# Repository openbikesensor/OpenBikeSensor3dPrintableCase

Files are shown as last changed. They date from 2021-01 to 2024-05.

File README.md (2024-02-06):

# OpenBikeSensor Case

This repository contains the 3d-printable models for OpenBikeSensor enclosures.

[Project Website](https://openbikesensor.org) |
[Model selection](https://www.openbikesensor.org/device/) (German) |
[3D printing instructions](https://www.openbikesensor.org/docs/hardware/general/case/) (German)

If you encounter any problems or have feature requests, please open an issue on
GitHub. If you need assistance related to the contents of this repository,
please ask in the [project forums](https://forum.openbikesensor.org).

## Cloning
If you want to build your own case using openscad instead of using the
readymade exports or if you want to start the customizer be aware
that you need to clone including git submodules:

```
git clone --recursive https://github.com/openbikesensor/OpenBikeSensor3DPrintableCase
# ... or if you forgot the --recursive argument, you can run this in the
# repository's directory later:
git submodule update --init --recursive
```

## About the files

We expect a recent version of OpenSCAD, for development we currently use OpenSCAD 2021.

This repository contains a lot of files for different options

* The `export/` folder contains the latest prebuilt `.stl` files for 3D printing.
  You can use those unless you want to make customizations. If you contribute
  changes to the models, you can refresh the models you changed using the
  ``make export-all`` command. If your ``openscad`` binary does not reside
  in ``/usr/bin/openscad`` you can specify its location by overriding the
  ``OPENSCAD`` variable like so (substitute your specific openscad path): ``make -j OPENSCAD=/Applications/OpenSCAD.app/Contents/MacOS/OpenSCAD``
* The `legacy/` folder contains old versions of the case, including lots of
  variants that were created but unmaintained. These were built with
  proprietary software packages and often available in their native format(s)
  and therefore mostly uneditable for most of the community. A lot of these
  files are also available in STEP format, and of course exported as STL for
  printing. We keep these files around for reference and convenience.
* The `lib/` folder contains common OpenSCAD files with library functions and
  modules, as well as exports of other objects that can be imported in the part
  files, e.g. to check dimensions.
* The `src/` folder contains OpenSCAD scripts for all parts. Not all parts are
  needed for printing a working enclosure. Please check the documentation
  (links on top) to assemble your custom list of parts for the variant you want
  to build.
* The `render/thumbnails/` folder contains rendered views of the parts. These images
  should be refreshed with changes to the parts using the `make thumbnails`
  command if you plan to submit your changes. They are used in this `README.md`.
* The `variables.scad` file contains all variables used in any of the parts.
  You can customize everything by editing this file, or passing new variable
  values on the OpenSCAD command line.

## The Standard Variant

There is a notion in the OpenBikeSensor community to label one combination of
parts and a certain version of the electronics the "Standard Model" (read about
it [here](https://www.openbikesensor.org/docs/hardware/general/models/)). This
is meant to get you started, without having to check for compatibility and
without cross referencing multiple parts of the documentation to build your own
version of the device.

> **Warning**
> We only keep the rail shapes constant between versions. When printing make sure that your ``MainCase`` and ``MainCaseLid`` come from the same release. The same is true for ``DisplayCase`` Top and Bottom. The Idea is that OpenBikeSensors can be mounted on a different bike with older version mounts, but the current version lid won't necessarily fit onto last years case.

To get a standard variant, print these parts:

```
MainCase/GpsAntennaLid
MainCase/MainCase
MainCase/UsbCover
MainCase/MainCaseLid
DisplayCase/DisplayCableStrainRelief (2x)
DisplayCase/DisplayCaseBottom
DisplayCase/DisplayCaseTop
Mounting/StandardMountAdapter
Mounting/SeatPostMount
Mounting/LockingPin
Mounting/HandlebarRail
```

## Compatibility

The parts are compatible with the OpenBikeSensor PCB Version `00.03.12`. Other
versions, both older and newer, might work, but are untested.

## Part list

This is a list of all available parts, and a description of what they are used for.

### Main case

The main case of the device enclosure. This will contain most of the
electronics. The core part are a `MainCase` and a `MainCaseLid`, which is
installed with five M3x8 bolts in the lid, matching the five threaded heatset
inserts in the body.

The PCB is installed into the main body with 3 heat-set inserts and M3x8 bolts.
One additional heat-set insert is required for the `GPSAntennaLid` (see below).
This totals 9 inserts to be placed after printing.

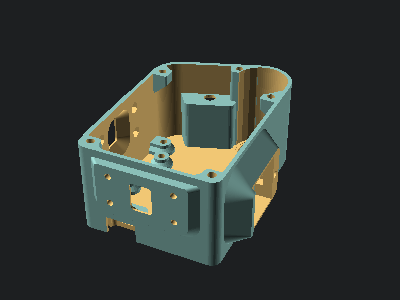
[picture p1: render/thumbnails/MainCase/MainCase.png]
MainCase/MainCase


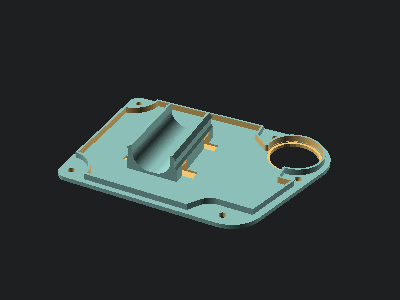
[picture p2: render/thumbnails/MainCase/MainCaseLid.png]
MainCase/MainCaseLid


#### GPS antenna lid

The `GpsAntennaLid` covers the part of the main enclosure with the GPS antenna.
It is held in place by only one M3x8 bolt and can be removed to reveal the
antenna, behind which there is an access hole for the Micro-USB receptable of
the ESP32 dev board -- very useful for debugging or developing the firmware.

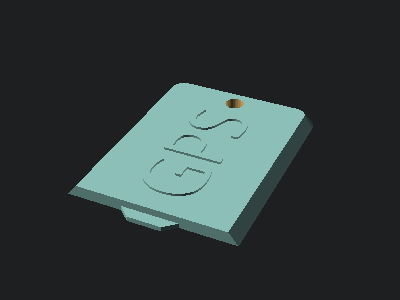
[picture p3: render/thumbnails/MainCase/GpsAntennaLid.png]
MainCase/GpsAntennaLid


#### USB-C port cover

The `UsbCover` is small plug for the USB-C port on the bottom of the device,
which is used for charging the battery. This plug is held in place by 2 pairs
of 3x3x3mm neodymium magnets.

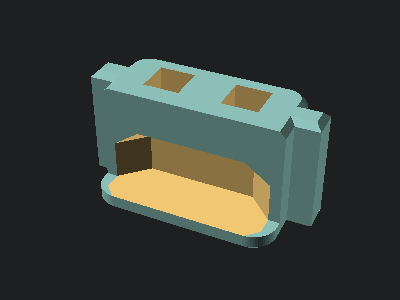
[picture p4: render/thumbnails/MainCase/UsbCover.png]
MainCase/UsbCover


### Display case

The display case consists of two halfs, `DisplayCaseTop` and
`DisplayCaseBottom`. The display case contains the I2C display and a push
button and is attached to the main device with a cable that exits through a
hole in the bottom part.

The bottom part contains 3 threaded heat-set inserts and a pocket for two
20x10x1.9mm neodymium magnets. The magnets hold the display in the rail on the
handlebar (see `HandlebarRail`).

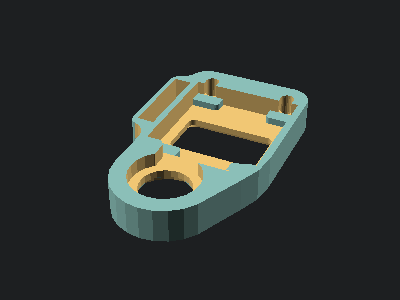
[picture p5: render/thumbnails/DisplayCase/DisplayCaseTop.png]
DisplayCase/DisplayCaseTop


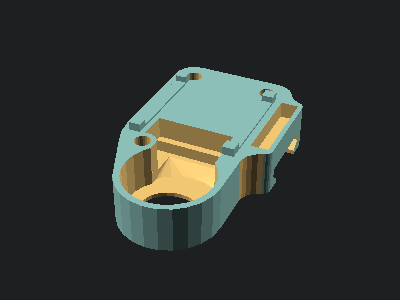
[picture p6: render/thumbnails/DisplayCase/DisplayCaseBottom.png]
DisplayCase/DisplayCaseBottom


#### Display cable strain relief

*Print two copies of this.*

The `DisplayCableStrainRelief` holds the display cable firmly in place inside
the display case to prevent strain on the solder joints or crimped connectors
inside. The two halves are pushed into the hole at an angle one after the
other, and then screwed together with two M3x8 bolts and hex nuts.

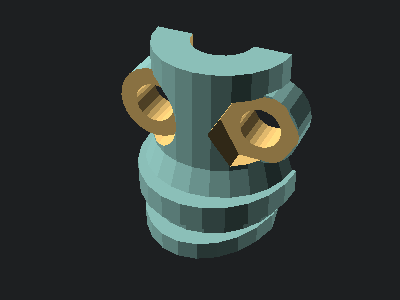
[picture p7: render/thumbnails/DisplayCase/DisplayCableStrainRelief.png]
DisplayCase/DisplayCableStrainRelief


### Mounting

#### Standard mount adapter

The `StandardMountAdapter` is screwed onto the main enclosure. It contains a
channel for the display cable to sit in, pressing it firmly against the outer
wall of the main case and relieving any strain from its connector inside.

This adapter is used to attach the device to the mount that is permanently
affixed to the bike. There may be different adapters in the future for
different attachment needs, but this one is the default.

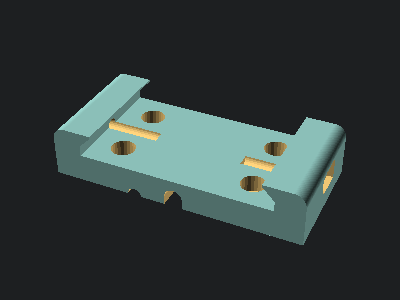
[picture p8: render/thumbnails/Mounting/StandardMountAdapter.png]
Mounting/StandardMountAdapter


#### Seat post mount

The `SeatPostMount` gets attached to the seat post of the bicycle with zip ties.

*Hint: A piece of an old bicycle tube can prevent it from turning or shifting.*

This is a counterpart to the `StandardMountAdapter`, which can slide onto this
part's rail and be held in place with a `LockingPin`.

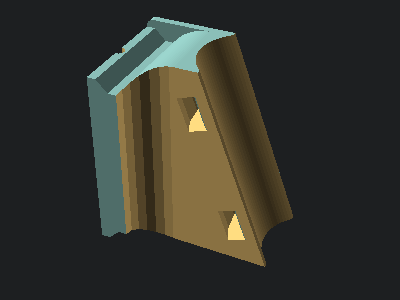
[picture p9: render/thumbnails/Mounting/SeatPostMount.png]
Mounting/SeatPostMount


#### Top tube mount

The `TopTubeMount` gets attached to the top tube of the bicycle frame, similar
to the seat post mount.

*Hint: A piece of an old bicycle tube can prevent it from turning or shifting.*

This is also compatible with the `StandardMountAdapter` and `LockingPin`. Make
sure to use a "Top Rider" variant main case (see below for details).

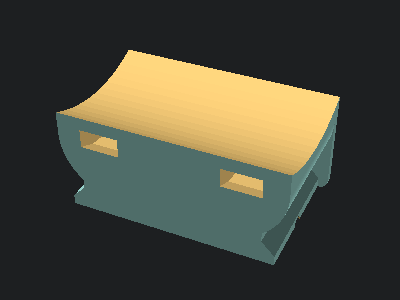
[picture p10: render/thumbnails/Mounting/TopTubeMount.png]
Mounting/TopTubeMount


#### Locking pin

Screw an M3x16 to M3x20 bolt through the `LockingPin` part, such that the
bolt's head sits on the long handle's side. Now you have a pin that you can
push into the hole in the `StandardMountAdapter` and turn 180 degrees, holding
the pin, and the device, in place.

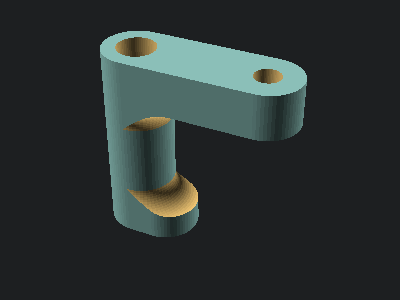
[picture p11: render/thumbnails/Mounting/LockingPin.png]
Mounting/LockingPin


#### Handlebar rail

Attach the `HandlebarRail` to the handlebar of your bike with two zip ties or a single
hose clamp. Again, a piece from an old bicycle tube can prevent turning and shifting.

The large wall contains a pocket for two 20x10x1.9mm neodymium magnets, pushed
in one after the other. Make sure to consider their polarity to match those of
the display. The display can now slide onto this rail and is held in place by
the magnets.

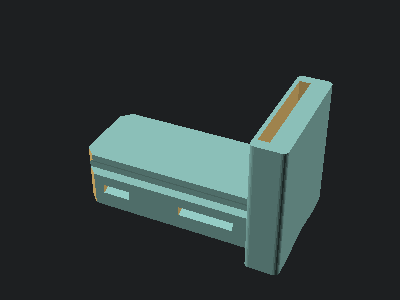
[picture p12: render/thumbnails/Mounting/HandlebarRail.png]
Mounting/HandlebarRail


An alternative Handlebar rail can be mounted like most bike computers with a
rubber o ring;
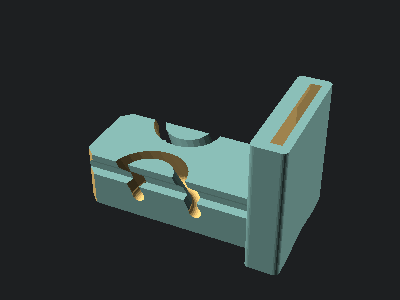
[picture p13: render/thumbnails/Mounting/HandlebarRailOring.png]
Mounting/HandlebarRailOring


Often you find magnets where one magnet is strong enough for your display - you
can use a platic decoy to save on magnets in these cases
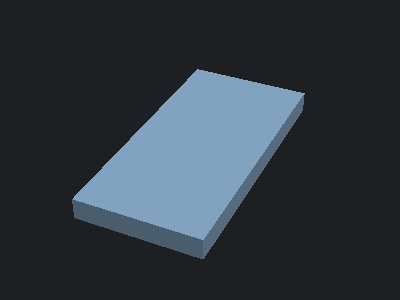
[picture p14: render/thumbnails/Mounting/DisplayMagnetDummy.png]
Mounting/DisplayMagnetDummy


#### Bike rack mount

The bike rack mount can be used to attach a "Top Rider" main case to a standard
bicycle rack. It consists of two parts, the `BikeRackMountSide` (which is
required twice) and `BikeRackMountCenter` or `BikeRackMountCenterLongitudinal`.

The side parts are mounted on the longitudinal rails of the rack, either above
or hanging below. They are connected with two rods (aluminium or wood) that
form cross beams, cut to sized depending on the width of the bike rack. In the
center of these rods sits the center piece, which has the attachment rail for
the sensor.

In a rotated version, the rods are aligned longitudinally, a difference center
piece (`BikeRackMountCenterLongitudinal`, third image) is used to rotate the
OBS correctly. Use this if you need your bike rack's longitudinal tubes for
attaching cargo, and you want to mount the OBS on the cross beams of the rack.

The rods can be affixed to the 3D printed parts by gluing them in place, once
they have been sized and fitted to your rack.

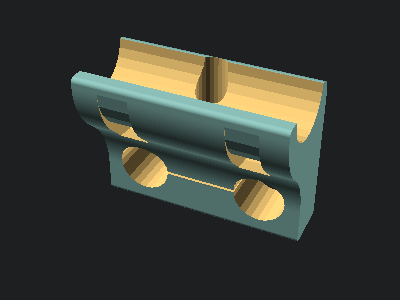
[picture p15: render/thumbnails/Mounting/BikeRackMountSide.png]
Mounting/BikeRackMountSide


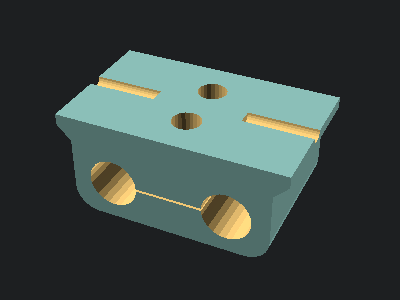
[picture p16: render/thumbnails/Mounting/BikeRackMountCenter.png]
Mounting/BikeRackMountCenter


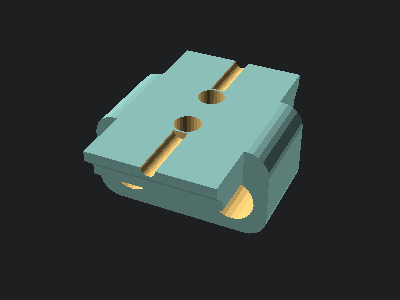
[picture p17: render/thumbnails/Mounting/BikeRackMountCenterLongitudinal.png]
Mounting/BikeRackMountCenterLongitudinal


#### Attachment cover

If you have a main case that has both attachment points (top rider and back
rider), you may want to cover the one of them that you are not using, such that
the screw holes and (optional) cable hole are not left open. The
`AttachmentCover` is a simple cover that fits the screw pattern.

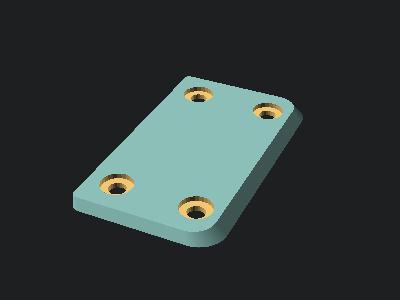
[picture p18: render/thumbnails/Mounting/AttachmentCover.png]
Mounting/BikeRackMountSide


#### Back rider to top rider adapter

This adapter allows the use of a "back rider" main case on a "top rider" mount.
Print a second locking pin as well.

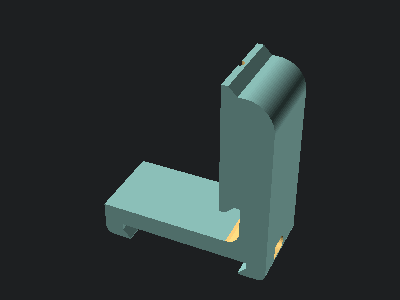
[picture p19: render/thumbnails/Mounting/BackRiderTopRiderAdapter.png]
Mounting/BackRiderTopRiderAdapter


## Customization

There are tons of variables in the `variables.scad` file, mostly dimensions,
which can be adjusted to suit your needs. Some of these variables are however
not necessarily wise to be changed, as other dimensions might inadvertently
depend on them, or they might produce invalid results in certain ranges.

However, some options are meant to be changed to suit your specific needs. The
defaults get you most of the way, but certainly, some users will need a
different set of features, so here is a list of options you might want to
change:

### Print settings

Some options exist to control sizes and features that have been added just for
3D printing ease. Configure these to match your printing setup. The defaults
should work for most printers, but if you modify your settings greatly (e. g.
to print faster), you might also need to change these model parameters:

```
extrude_width
enable_easy_print
layer_height
default_clearance
```

### Top Rider vs. Back Rider

A "top rider" variant main case has an attachment port on the bottom (when
mounted), while a "back rider" has it on the front. The "traditional" OBS case
therefore is a back rider variant, as it used to always sit behind the seat
post, attached horizontally. However, many cyclists configure their bikes in a
way that there is not enough room for a whole OBS below the seat, so a
different way of attaching the OBS is needed.

Top riders can sit on the top tube, the luggage rack, or anywhere else where
there is support from below. Moving the attachment point on the main case makes
it simple to design compatible mounts with their rail on top, without a
complicated structure that "goes up and around" to provide a backwards-facing
rail.

A single case can have both top rider and back rider attachment ports. They
don't necessarily need to have an adapter attached, though it is recommended to
do so in order to fill the screw and cable holes.

To configure whether to generate top and/or back riders, set the following
variables. The `_cable` variables control whether the corresponding attachment
port (if it exists) has a hole for the cable or not.

```
MainCase_back_rider
MainCase_top_rider
MainCase_back_rider_cable
MainCase_top_rider_cable
```

The `Mounting/BackRiderTopRiderAdapter` is available for people who have a back
rider and would like to use a top rider mount. The opposite is not available.

### Dimensions

* General
  * `m3_screw_diameter_loose`: A hole for an M3 bolt has this diameter. The
    bolt is not meant to grab this hole, but slide into and out of it ("loose"
    fit). For (almost) each bolt, there is a corresponding threaded metal part
    (nut or insert), so increase this value if your bolts are hard to get where
    they need to go. Print `Calibration/ScrewHoles` to find a good value for
    your printer.
  * `m3_hex_nut_diameter`: The outer circle around a hex nut's hexagon has this
    diameter. This is **not** the same as the "wrench size" from [DIN
    934](https://www.fasteners.eu/standards/DIN/934/) (dimension `S`), but its
    nominal value is `2 / sqrt(3) * S`. For M3, this equals `6.35mm` nominally.
    Increase this for more clearance. Print `Calibration/HexNuts.stl` to find a
    good value for your printer.
* `SeatPostMount`
  * `SeatPostMount_angle`: Set to the angle that your seat post is away from
    the vertical in degrees (usually around 20). This ensures that the device
    will sit horizontally behind the seat post.
  * `SeatPostMount_diameter`: Set to the diameter of your seat post (in mm).
    The default for most bicycles today is 28.
  * `SeatPostMount_length`: Increase this to lengthen the mount,
    shifting the device further backwards on your bike. You might consider
    angular force, so don't set it too high, but this can help if your mount is
    hard to reach, or if the device disappears underneath your seat,
    potentially blocking GPS signal.
* `HandlebarRail`
  * `HandlebarRail_tube_radius`: The radius (half diameter) of your handlebar,
    in mm.

### Logo customization

The `Makefile` supports generating the case with different logos. For now, the
only parts that are customizable with logos are `MainCase/MainCase` and
`MainCase/MainCaseLid`. Please check the instructions in
[`logo/README.md`](./logo/README.md) for creating your own logo version.

## Legacy parts

The files of legacy versions are available in the ``.stl`` format for 3D
printing. But these are discretized versions of more universal 3D Geometry that
can be read and edited by CAD software.

This is a grown project and in the past contributions have been made with
different CAD Programs. Some parts were designed/modified in Autodesk inventor
(filenames `*.ipt`), some were designed in Fusion360 (filenames `*.f3d`), but
for most parts a step file (`*.stp, *.step`) is available which can be opened
by most CAD Programs. For your contributions in CAD software of your choice it
would be great if you could also follow the practice of submitting your changes
in both `.stl` for 3D-Printing and `.step` for later editing - and maybe the
native format of your CAD software on top.

OpenSCAD is a special case of course: Here submitting `.stl` (for now) and the
`.scad` file is sufficient. 

### Customizer webservice

To run the customizer webservice you run it from the dockerfile (and be sure
that you cloned the repo recursively before building the cointainer:

```
git submodule update --init --recursive
docker build . -t customizer
docker run --rm -p 8001:80 customizer 
```

Whereafter you should be able to access your customizer on your host on port 8001.

Alternatively you can launch the python module directly using uvicorn,
but that is only recommended for dev setups an d will be described
in the module readme.

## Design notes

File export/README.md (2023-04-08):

# For the most recent release you can find the files conveniently zipped [here under "assets"](https://github.com/openbikesensor/OpenBikeSensor3dPrintableCase/releases)

This folder contains the stl files for convenience. It is recommended however to download the latest released files as a zipped bundle [here under "assets"](https://github.com/openbikesensor/OpenBikeSensor3dPrintableCase/releases) instead.

> **Warning**
> We only keep the rail shapes constant between versions. When printing make sure that your MainCase and Lid as well as DisplayCase Top and Bottom come from the same case version. The Idea is that OpenBikeSensors can be mounted on a different bike with older mounts, but the current version lid won't necessarily fit onto last years case.

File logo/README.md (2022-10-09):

# Logo generator

This folder contains logo files to be generated into the STL files, adding a
customizable logo to your cases. The script generates a "main" part and a
"highlight" part, where the main part is the normal case file with the logo cut
out, and the "inner" part is the logo. This can be used in multi-part printing,
e.g. in Prusa Slicer or Ultimaker Cura. In general you will need to follow these steps:

* Find your logo as a vector graphics file (e.g. SVG)
* Scale the logo to the right dimensions, using the frame templates
* Choose inverted or normal mode, and a logo thickness
* Generate the STL files with GNU make
* Import the two STL files into your slicer as a multipart print, or print just
  the main part with a color change at an early layer
  
The script will only work on linux.

## Features

* Use any vector graphics, simple placement in template
* Inverted or normal style logo
* Customize logo depth (number of layers)
* Auto generate in Makefile

## Guide

### Preparing the logo

* Open the logo you would like to use in [Inkscape](https://inkscape.org/)
* Make sure the logo is only a shape path. Colors, gradients and even the
  thickness of lines are ignored. Use the options in the "Path" menu of
  Inkscape, e.g. "Object to Path" and "Union", to generate a single path
  object. Remove its border, fill it black.
* Duplicate `logo/template` to `logo/MyLogoName` (choose a name) and edit the
  files in this folder in Inkscape, copy-paste your logo into it. Transform the
  logo to place it where you would like to print it.
* Delete the gray frame shape, leaving only a correctly sized document with the
  logo placed where you want it.

### Choosing options

Depending on your logo shape and the colors you are going to use it to print,
you might want to **invert the logo**. For an inverted logo, the space
surrounding the logo is separated for printing, the logo becomes part of the
main body instead. Use this

* when you want to print the logo and body in the same color, or
* when your logo should be printed in an translucent filament and the space
  around it should be covering in an opaque filament (the combination of two
  translucent filaments is discouraged as the colors mix and look ugly), or
* depending on the shape of your logo, e.g. when very thin features or acute
  angles are present and you want to influence the printing order.

If you use a custom layer height other than 0.2mm, or you need more layers of
logo, change the corresponding variables in `variables.scad`. Some opaque
filaments could work if just one layer is applied, but for best results, at
least two layers should be chosen. Each layer will need a filament change
though, so try to keep the number of layers low. The default example is a 0.2mm
layer height, and two layers of logo printing, which results in a logo depth of
0.4mm.

### Generate the STL files

The following make targets are available:

```bash
make logos # generate all logo files
make logo-MyLogoName # generate all files for the logo in logo/MyLogoName
make logo-MyLogoName-normal # only normal mode
make logo-MyLogoName-inverted # only inverted mode
```

The files generated are placed here:

```
export/logo/$logo_name/MainCase-$mode-main.stl
export/logo/$logo_name/MainCase-$mode-highlight.stl
```

A pair of two such files forms the whole case, where the `main` file is the
normal body of the object (case or lid), and the `highlight` file is the
cut-away part. Import both simultaenously into your slicer to form a multi-part
object for multi-color printing.

The `$mode` can be "normal" or "inverted". An inverted logo is used if the
color of the logo should match the color of the walls and remainder of the
object, effectively printing the bottom side (while printing) in a different
color, *except* for the logo. This may be easier to print or desired for
aesthetical reasons, depending on the logo and filaments you use.

### Importing into Prusa Slicer

If you're not using Prusa Slicer or a derivative thereof, you will need to find
your own solution. If you are using Ultimaker Cura, see below.

For Prusa Slicer, multipart printing is very simple to set up, if your printer
supports any type of command to switch filaments.  Marlin firmware can be
compiled for most printers with support for the M600 command. Printers with
physical support for multi-material printing of course should be supported out
of the box.

* Import the `export/logo/MyLogoName/MainCase-normal-main.stl` (or *inverted*
  instead of *normal*) file into Prusa Slicer as usual. It should be placed in
  the center of your build plate automatically.
* In the right sidebar, locate your part. Under "Editing", click the icon, then
  choose "Add Part" > "Load...", and select the corresponding
  `...-highlight.stl` file.
* You now have a multipart print. Configure everything as normal.
* If your printer only has one extruder, but supports the M600 command, you can
  still choose 2 extruders under "Printer Settings" > "General" >
  "Capabilities" > "Extruders". In the "Custom G-Code" section, under "Tool
  change G-code", you might have to enter `M600`.
* You should then be able to choose the two extruders for the different parts
  in the parts list in the right sidebar. This way the slicer generates
  separate toolpaths for both parts in each layer, and places the M600 command
  in between those paths. The printer will then pause and wait for the user to
  change the filament and confirm to resume.

If you don't mind multiple gcode-Files, your printer does not support `M600` and
your nozzle shape allows you to print around multiple layers, you can export the
gcode for each color by turning the other part into a support blocker. If the bed
keeps being heated after the print (eg. no `M140 S0` command at the end of the print),
you can change filament and start with the next file. Printing brims can be problematic
if the printed part only touches the build plate on smaller areas than the rest of the
body does.

### Importing into Ultimaker Cura

To print in Ultimkaer Cura with two colors, follw these steps:
* Click on the folder in the upper left corner and choose the first file. Make sure that on the left side extruder 1 is selected.
* Click again on the folder and choose the second file. Now select extruder 2 on the left side. Both files should now be visible next to each other.
* Select both parts (click, hold shift and click on the other part). Rightclick to bring up the context menu, select `Merge Models`.
* Normally, they should align now. If not, align them manually.
* Press `slice` and continue as normal.

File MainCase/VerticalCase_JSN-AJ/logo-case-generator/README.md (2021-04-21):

# Logo Case Generator

This is a tool made with OpenSCAD, to take the main case or lid file and add a logo to
it. The script generates a "main" part and a "inner" part, where the main part
is the normal case file with the logo cut out, and the "inner" part is the
logo. This can be used in multi-part printing, e.g. in Prusa Slicer. In general
you will need to follow these steps:

* Find a logo as a vector graphics file (e.g. SVG)
* Scale the logo to the right dimensions, using the frame template
* Choose inverted or normal mode, and a logo thickness
* Generate the two STL files
* Import the two STL files into your slicer as a multipart print, or print just
  the main part with a color change at an early layer

## Features

* Use any vector graphics, simple placement in template
* Inverted or normal style logo
* Customize logo depth (number of layers)
* Only generates a lid for now, will be extended for the main case as well

## Guide

### Preparing the logo

* Open the logo you would like to use in [Inkscape](https://inkscape.org/)
* Make sure the logo is only a shape path. Colors, gradients and even the
  thickness of lines are ignored. Use the options in the "Path" menu of
  Inkscape, e.g. "Object to Path" and "Union", to generate a single path
  object. Remove its border, fill it black.
* Open `frame-lid.svg` or `frame-maincase.svg` in Inkscape and copy-paste your logo into it. Transform the
  logo to place it where you would like to print it.
* Delete the gray frame shape, leaving only a correctly sized document with the
  logo placed where you want it.
* Save the file as a different file, in this example we'll use `my-logo-framed.svg`.

### Choosing options

Depending on your logo shape and the colors you are going to use it to print,
you might want to **invert the logo**. For an inverted logo, the space
surrounding the logo is separated for printing, the logo becomes part of the
main body instead. Use this 

* when you want to print the logo and body in the same color, or
* when your logo should be printed in an translucent filament and the space
  around it should be covering in an opaque filament (the combination of two
  translucent filaments is discouraged as the colors mix and look ugly), or
* depending on the shape of your logo, e.g. when very thin features or acute
  angles are present and you want to influence the printing order.

You will also need to choose a thickness, or `logo_depth`. This should be a
multiple of your layer height. Some opaque filaments could work if just one
layer is applied, but for best results, at least two layers should be chosen.
Each layer will need a filament change though, so try to keep the number of
layers low. The default example is a 0.2mm layer height, and two layers of logo
printing, which results in a logo depth of 0.4mm.

### Generate the STL files

First, you need to have [OpenSCAD](https://openscad.org/) installed.

Run the following commands:

```bash
openscad -D 'mode="main"' -D 'logo_file="my-logo-framed.svg"' -D 'logo_depth=0.4' logo-lid.scad -o lid-my-logo-main.stl
openscad -D 'mode="inner"' -D 'logo_file="my-logo-framed.svg"' -D 'logo_depth=0.4' logo-lid.scad -o lid-my-logo-inner.stl
```

If you chose an inverted logo, also add `-D 'inverted=true'` to both
commands. If your logo is a very complex shape, and the result looks wrong, try
setting and increasing the `logo_convexity` parameter as well, from its default
10 upwards, e.g. to 20 or 30.

You can also combine the inverted `inner` with a with an inverted `main` with 
`-D 'logo_file="empty_logo.svg"'` to achieve a bridged logo with multiple files.

### Importing into Prusa Slicer

If you're not using Prusa Slicer or a derivative thereof, you will need to find
your own solution.

For Prusa Slicer, multipart printing is very simple to set up, if your printer
supports any type of command to switch filaments.  Marlin firmware can be
compiled for most printers with support for the M600 command. Printers with
physical support for multi-material printing of course should be supported out
of the box.

* Import the `lid-my-logo-main.stl` file into Prusa Slicer as usual. It should
  be placed in the center of your build plate automatically.
* In the right sidebar, locate your part. Under "Editing", click the icon, then
  choose "Add Part" > "Load...", and select the `lid-my-logo-inner.stl` file.
* You now have a multipart print. Configure everything as normal.
* If your printer only has one extruder, but supports the M600 command, you can
  still choose 2 extruders under "Printer Settings" > "General" >
  "Capabilities" > "Extruders". In the "Custom G-Code" section, under "Tool
  change G-code", you might have to enter `M600`.
* You should then be able to choose the two extruders for the different parts
  in the parts list in the right sidebar. This way the slicer generates
  separate toolpaths for both parts in each layer, and places the M600 command
  in between those paths. The printer will then pause and wait for the user to
  change the filament and confirm to resume.

If you don't mind multiple gcode-Files, your printer does not support `M600` and 
your nozzle shape allows you to print around multiple layers, you can export the 
gcode for each color by turning the other part into a support blocker. If the bed 
keeps being heated after the print (eg. no `M140 S0` command at the end of the print), 
you can change filament and start with the next file. Printing brims can be problematic
if the printed part only touches the build plate on smaller areas than the rest of the 
body does.

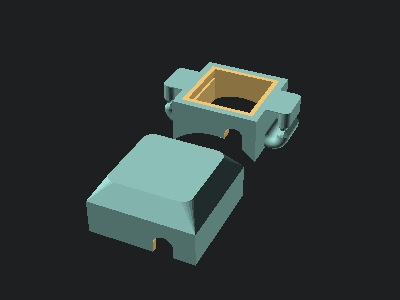
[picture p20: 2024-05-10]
render/thumbnails/LiteCase/HandlebarButton.png

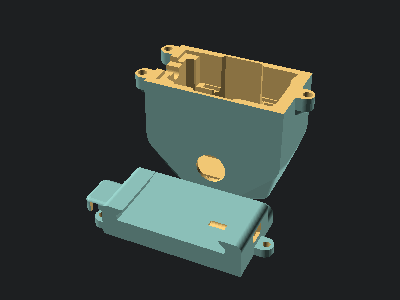
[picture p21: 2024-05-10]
render/thumbnails/LiteCase/LiteCase.png

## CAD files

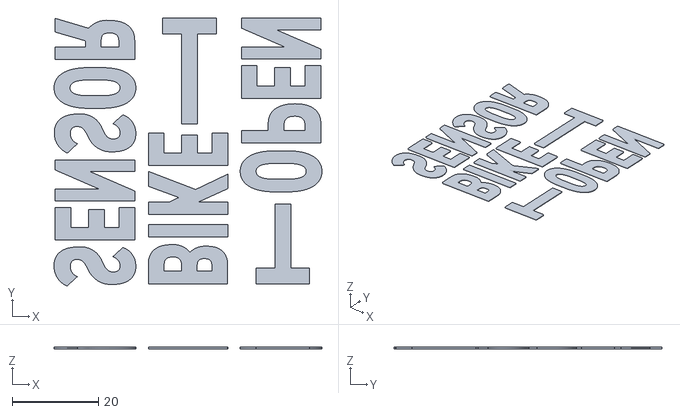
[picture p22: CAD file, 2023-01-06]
export/logo/OpenBikeSensor/MainCase-normal-highlight.stl
62.2 x 62.2 x 0.4

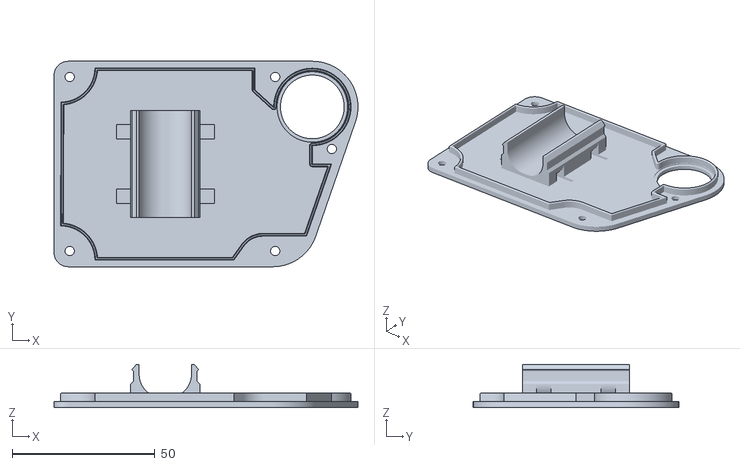
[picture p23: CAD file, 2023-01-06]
export/MainCase/MainCaseLid.stl
106.5 x 72.0 x 15.1

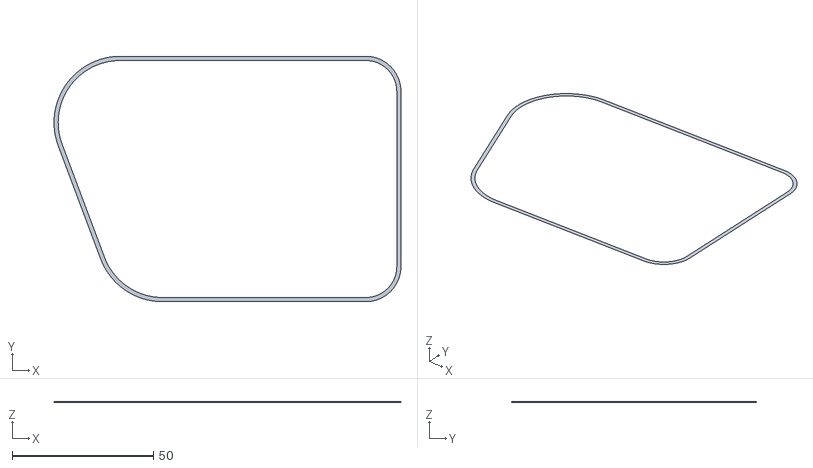
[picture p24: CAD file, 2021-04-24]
MainCase/VerticalCase_JSN-AJ/experimental/manual_brim_for_maincase.stl
123.0 x 87.0 x 0.2

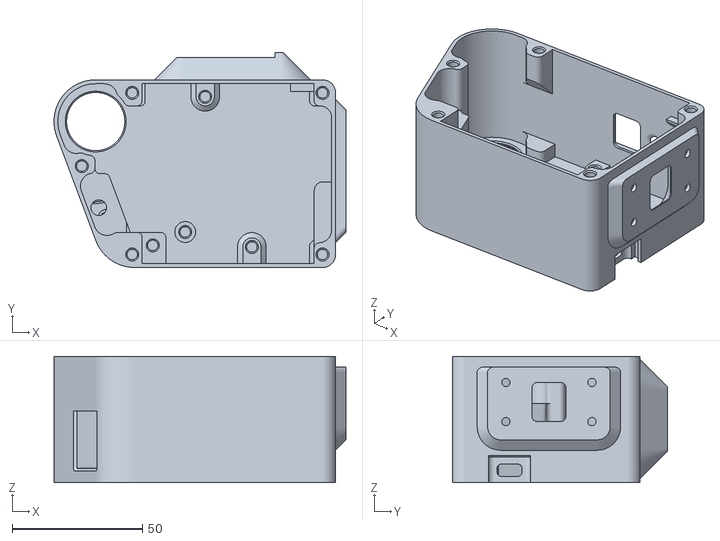
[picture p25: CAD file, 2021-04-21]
MainCase/VerticalCase_JSN-AJ/experimental/OBS-MainCase-A-001_MainCase_without_logo_v0.1.0.stl
112.0 x 82.5 x 48.4

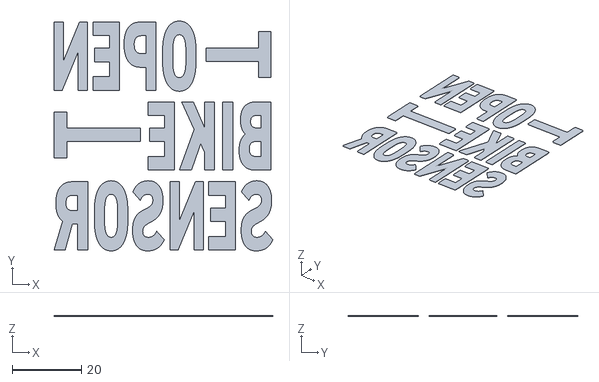
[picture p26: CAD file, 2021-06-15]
MainCase/VerticalCase_JSN-AJ/OBS-MainCase-B-002_Lid_with_0.4mm_OBS-logo_v0.1.0_bottom.stl
63.1 x 66.2 x 0.4

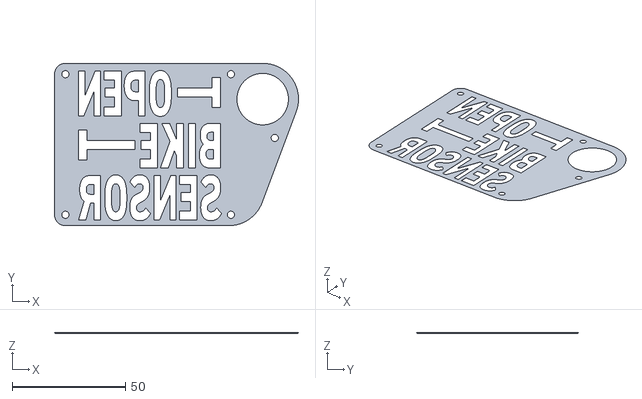
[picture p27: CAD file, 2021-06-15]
MainCase/VerticalCase_JSN-AJ/OBS-MainCase-C-002_Lid_v0.1.0_with_0.4mm_OBS-logo_bottom-inverted.stl
107.6 x 71.6 x 0.4

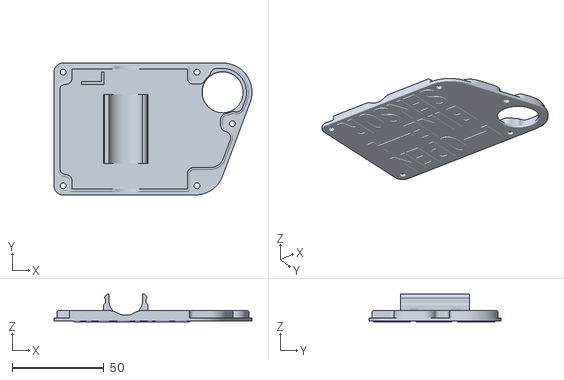
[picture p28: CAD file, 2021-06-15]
MainCase/VerticalCase_JSN-AJ/OBS-MainCase-C-002_Lid_v0.1.0_with_0.4mm_OBS-logo_top-inverted.stl
108.0 x 72.0 x 15.1

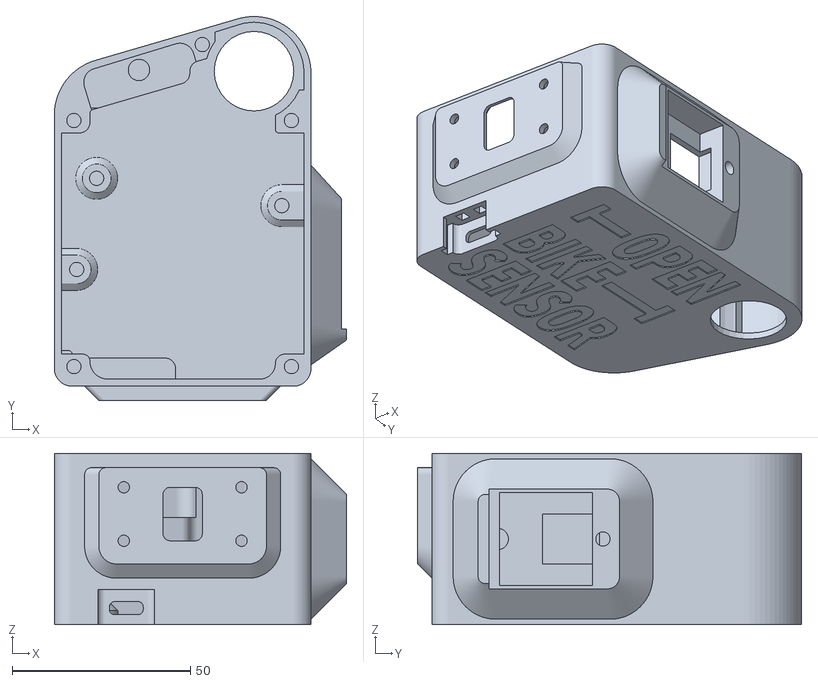
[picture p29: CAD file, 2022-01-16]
export/logo/OpenBikeSensor/MainCase-normal-main.stl
82.0 x 107.7 x 48.0

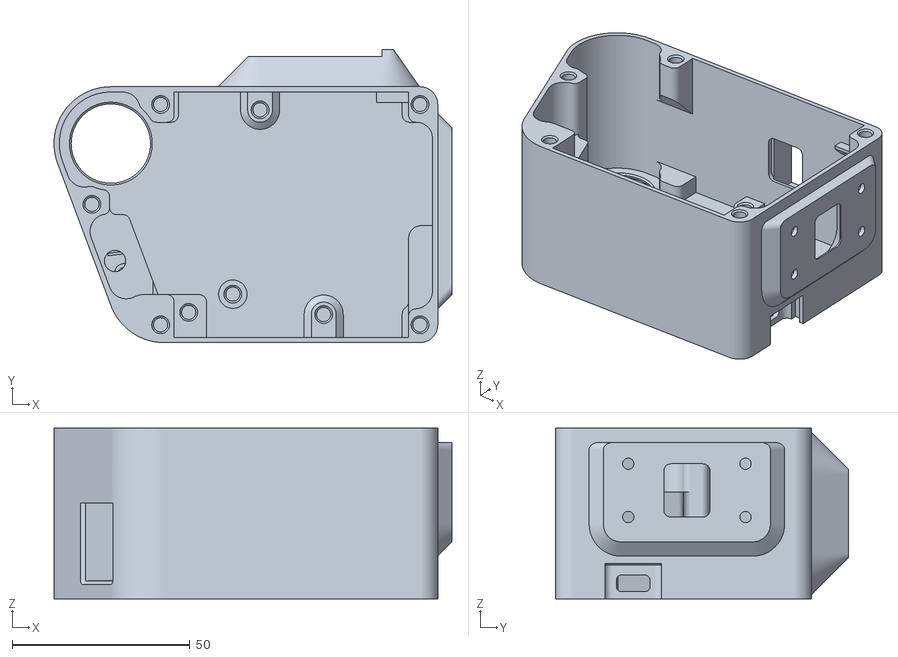
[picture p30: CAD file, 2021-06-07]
MainCase/VerticalCase_JSN-AJ/OBS-MainCase-D-001a_empty_logo_top.stl
112.0 x 82.5 x 48.0

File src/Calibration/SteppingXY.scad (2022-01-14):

// The object generated by this file can be used to print a calibration cross
// of known target size, in order to compute the correct steps/mm values for
// the printer. The positive x-axis arm has a little mark in it, make sure to
// align it correctly in your slicer or remember the alignment when you take it
// off your print bed.
//
// Please print this and calibrate your printer step settings, such that all
// dimensions print correctly, before using any of the other calibration tools.
// This object does not measure your z distance (that would print way too
// long), but it is much easier to manually move your print head along z
// through G-code and measure the resulting height change, compared to good
// horizontal measurements.

use <../../lib/Calibration.scad>

length = 100;
width = 5;
height = 0.8;

union() {
  difference() {
    translate([0, 0, height/2])
    cube([length, width, height], true);

    translate([length/2 - width/2, 0, height])
    cylinder(d=min(1.5, width/2), h=height, center=true, $fn=32);
  }

  rotate([0, 0, 90])
  translate([0, 0, height/2])
  cube([length, width, height], true);
}

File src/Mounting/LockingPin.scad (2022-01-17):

include <../../variables.scad>

// $fa = 1;
// $fs = 0.1;
$fn = 64;

module LockingPinRoundRect(h, l) {
  hull() {
    cylinder(h=h, d=LockingPin_diameter);

    translate([l - LockingPin_diameter, 0, 0])
    cylinder(h=h, d=LockingPin_diameter);
  }
}

module LockingPinFillet(handle_length) {
  intersection() {
    difference() {
      LockingPinRoundRect(LockingPin_fillet_radius, handle_length);

      // fillet on foot
      translate([0, 0, LockingPin_fillet_radius])
      rotate_extrude()
      translate([LockingPin_diameter/2 + LockingPin_fillet_radius, 0, 0])
      circle(r=LockingPin_fillet_radius);
    }

    cylinder(r=LockingPin_diameter / 2 + LockingPin_fillet_radius, h=LockingPin_fillet_radius);
  }
}

module LockingPin() {
  difference() {
    union() {
      // base cylinder
      cylinder(h=LockingPin_height, d=LockingPin_diameter);

      // foot
      translate([0, 0, LockingPin_height - LockingPin_foot_height])
      LockingPinRoundRect(LockingPin_foot_height, LockingPin_diameter + LockingPin_fillet_radius);

      // handle
      LockingPinRoundRect(LockingPin_handle_height, LockingPin_handle_length);

      // handle fillet
      translate([0, 0, LockingPin_handle_height])
      LockingPinFillet(LockingPin_handle_length);

      // foot fillet
      translate([0, 0, LockingPin_height - LockingPin_foot_height])
      mirror([0, 0, 1])
      LockingPinFillet(LockingPin_diameter + LockingPin_fillet_radius);
    }

    // holes
    union() {
      // hole in handle, for wire attachment
      translate([LockingPin_handle_length - LockingPin_diameter, 0, -1])
      cylinder(d=LockingPin_small_hole_diameter, h=LockingPin_handle_height+2);

      // hole in main shaft, for holding screw
      translate([0, 0, -1])
      cylinder(d=m3_screw_diameter_tight, h=LockingPin_height+2);
    }
  }
}

if (orient_for_printing) {
  LockingPin();
} else {
  translate([0, 0, LockingPin_height])
  rotate([180, 0, 0])
  LockingPin();
}

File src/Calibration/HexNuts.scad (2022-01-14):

use  <../../lib/Calibration.scad>

HolePatternM3HexNut();

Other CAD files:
MainCase/VerticalCase_JSN-AJ/OBS-MainCase-D-002_Lid_v0.1.0_empty_logo_top.stl
export/logo/OpenBikeSensor/MainCaseLid-inverted-main.stl
export/logo/OpenBikeSensor/MainCaseLid-normal-highlight.stl
export/logo/OpenBikeSensor/MainCaseLid-inverted-highlight.stl
export/logo/OpenBikeSensor/MainCaseLid-normal-main.stl
MainCase/VerticalCase_JSN-AJ/OBS-MainCase-B-002_Lid_v0.1.0_with_0.4mm_OBS-logo_top.stl
export/logo/OpenBikeSensor/MainCase-inverted-highlight.stl
export/logo/OpenBikeSensor/MainCase-inverted-main.stl
MainCase/VerticalCase_JSN-AJ/OBS-MainCase-A-001_MainCase_without_logo_v0.1.4.stp
src/Calibration/ScrewHoles.scad
DisplayCase/DisplayCase32mm/KnopfZusammenbau.iam
DisplayCase/DisplayCase32mm/Oberschale.ipt
DisplayCase/DisplayCase32mm/Oberschale.stl
DisplayCase/DisplayCase32mm/Schelle32.ipt
DisplayCase/DisplayCase32mm/Schelle32.stl
DisplayCase/DisplayCase32mm/Zwischenstueck.ipt
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

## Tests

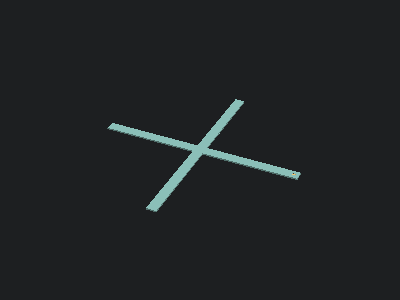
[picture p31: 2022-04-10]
render/thumbnails/Calibration/SteppingXY.png

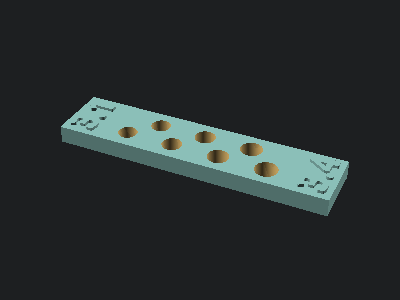
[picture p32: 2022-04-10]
render/thumbnails/Calibration/ScrewHoles.png

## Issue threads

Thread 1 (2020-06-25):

Reduce Number of Screws

tobst, 2020-06-25:
Choose a minimum of total screws as well as a minimum of different types. If possible, choose screws that are widely available (hardware store, etc.).

opatut, 2022-01-16:
The current version takes only M3x8 screws and a single M3x18 screw (I think) for the locking pin. There is still a need for corresponding nuts and heatset inserts, but this is way better than before. No more M3x45 screws, which are useless for any other project and not included in the ususal amazon M3 bolt collection packages etc. ;)

I think we can close this.

Closed 2022-01-16.

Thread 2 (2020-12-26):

Include a hole under magnet housing to be able to slide magnets out of their housing

rotger711, 2020-12-26:
In this version it is not possible to get the two magnets out of their housing. With a hole in the middle under the magnet housing this is made possible. Necessary if two OBS systems and sliding fixture are exchanged with opposite magnet (south / north) orientation.

opatut, 2022-01-16:
We're talking about the display rail here, I think. A hole was added long ago and it is also present in the `openscad` version.

Closed 2022-01-16.

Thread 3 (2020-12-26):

change OBS holding device

mega-stoffel, 2020-12-26:
The current OBS holding device has a gap in it to keep the holding screw. I'd suggest to make this gap over the whole width of this device.
The advantage would be, to be able to turn the holding device around and mount the OBS in a tilted position. I hope, to get a better GPS position, if the OPS is not looking directly into my body, but a bit more into the clear sky.

opatut, 2022-01-16:
It has been mirrored to the other side for a while now.

Closed 2022-01-16.

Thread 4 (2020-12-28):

Simons Gehäuse braucht 3-4mm mehr Höhe

Halbelunge, 2020-12-28:
Prozessor kollidiert mit Akku im Deckel wenn die Leiste zu hoch ist.

opatut, 2022-01-16:
I think this is solved by using actually the right SMD headers.

Closed 2022-01-16.

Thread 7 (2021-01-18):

GPS Antennenposition

Steffeng5, 2021-01-18:
wegen 3D Druck Präzisionsproblemen könnte die Antenne fürs GPS auch von oben eingeführt werden, da diese ja sowieso mit einer Deckplatte abgedeckt wird. So ist es nicht zwingend nötig auf Zehntel Millimeter genau zu drucken

mdoersam, 2021-01-18:
Wäre es ok, dann die Möglichkeit, das Gehäuse an der Stelle zu montieren komplett zu entfernen? Nach unserem Gespräch heute war das ja anscheinend sowieso nicht mehr der Fall

opatut, 2022-01-16:
Das wurde längst umgesetzt :tada:

Closed 2022-01-16.

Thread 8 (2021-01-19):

DisplayParts in VerticalCase Directory

Steffeng5, 2021-01-19:
There are display mount parts in /MainCase/VerticalCase/. By mistake I think?

mdoersam, 2021-01-19:
Can you list the filenames for easier confirmation?

Steffeng5, 2021-01-19:
OBS-A-001-AlternativeMount22mmSlide.stl
OBS-A-002-AlternativeMount22mmTop.stl
OBS-A-003-AlternativeMount22mmBottom.stl

Closed 2022-01-16.

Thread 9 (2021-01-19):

Add One Layer to "with LED holes" variant

Steffeng5, 2021-01-19:
For better water resistance there should maybe one 0.2mm layer to cover the LED holes. This should be thin enough to see the leds but protect against rain.

mdoersam, 2021-01-19:
Not sure how needed this might be.
Plan A is to add hot glue to plug the holes and have it transparent.
Plan B could be to just add a small modifier in the Slicer and have your effect if someome doesn't want to go the hotglue-route

opatut, 2022-01-16:
Superseded by #35.

Closed 2022-01-16.

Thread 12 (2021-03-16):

More clearance for PCB

opatut, 2021-03-16:
The current case fits the PCB exactly. We should add some clearance, so that on inexact prints or a bit oversize PCBs (cheap manufacturers from china don't always mill it to spec) don't sit too tightly. There is no reason for not adding some clearance around it, it is mounted securely using 3 bolts, and we have enough space to work with. I'd say ~0.5mm in each direction should be good.

The tight fit (pressing in the PCB) might result in damage or stress and later damage in soldering joints.

opatut, 2022-01-16:
This was done in the legacy versions already and also implemented in openscad.

Closed 2022-01-16.

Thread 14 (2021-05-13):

More clearance for magnet holes

gluap, 2021-05-13:
It would be great to add .1mm to .2mm of clearance to the magnet holes in all directions. Currently the holes are designed exactly to dimension of the magnets. But in 3D printing, especially at higher layer heights used by most people for larger objects this makes it very hard to slide the magnets in. The reason is that even with a well-calibrated printer the edges of each layer resemble a semicircle (or circular sector). And while the "average edge of deposited material" will be on-spot for a perfectly calibrated printer, the bellies of the circles or circle-sectors unavoidably protude beyond the planned edge of the layer, making the hole slightly smaller.

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

I know that this can be compensated for in some slicers ("enlarge holes in layers" type settings). However the setting it does not apply to all orientations of printing (because in some orientations the slicer does not detect the magnet holes as "holes" as they are not holes in the topographic sense. E.g. the pocket for the magnet in the display case.).

Mario (who is printing most of our cases) has locally modified the models to have more clearance, but it would be great if there was a bit of space to wiggle the magnets in the upstream model, as it would avoid a lot of test-prints on the user side. While a too-big hole can be compensated for by a bit of cyanacrylate or even a leftover piece of brim wedged in on the side, a too-small hole is hard to enlarge when it is only 3mm wide and its opening even smaller.

Alternatively if there is a proven method to wiggle the magnets in, this could be documeneted. The Issue I have is that Neodymium magnets aren't supposed to be heated above the 80°C that are needed to soften PETG.

I would have put this in terms of a pull request but I believe the current version of the Fusion360 files aren't in the repo yet.

opatut, 2021-05-13:
I totally agree.

> Neodymium magnets aren't supposed to be heated above the 80°C that are needed to soften PETG

I've heard of people successfully "soldering" them in place though. I can't promise it, but apparently for a short duration it doesn't totally wreck them.

> I would have put this in terms of a pull request but I believe the current version of the Fusion360 files aren't in the repo yet.

It's difficult, yeah. The latest modifications were, I think, done in Inventor from importing the step model, or something like that. There is sadly zero support for a PR-based workflow with these software packages, even exporting and importing fusion projects is a pain. We're looking into alternatives. Do you know of any good ones?

gluap, 2021-05-13:
@opatut No, I don't know a better solution for versioning 3d models. Unless one manages them in the workflow of one of the software packages (I believe fusion allows collaboration on models, but have no experience in using it), versioning of 3D models mostly comes down to managing binary blobs. Merging is impossible so the workflow with the least overhead is when one person manages the model. Some VCSes allow exclusive checkouts for this kind of work to ensure only one person at a time can work on un-mergable file format. Git is not one of them though.

Another possible path would be to build the model entirely in openscad (where everything is source code and thus merges are easy). But in my experience that becomes painful because of very long render times when one approaches the complexity of the cases. Also the learning curve of openscad is rather steep.

tobst, 2021-05-20:
Attempted to fix by  73d93de4da1ab3c2d892554190c8c89588ca5360
However I see the risk of tuning it just to my printer now.

tobst, 2021-05-20:
I added 0.1mm in all directions, but magnets can be pulled out with the counterpart now.

gluap, 2021-05-20:
With 0.15mm I added to the step file for experiments I observed that magnets could be pulled out, too. As stated above however I think a hole that works on most printers but needs glue (or a bit of brim wedged in) is preferrable to one that needs lots of test prints going to the garbage on most printers. Ill print the update tonight to see how it works out here. 0.1mm sounds snug but still insertable. Before I wasn't able to build the display cases at all without modification, the magnet just wouldn't drop into the recess no matter what.

tobst, 2021-05-20:
Should we supply an scad script to extract the critical part into a small test object which can be printed in a few minutes?

gluap, 2021-05-20:
I usually cut the interesting sections out in the slicer. If the model position can be assumed as fixed though, an openscad script could be provided that directly enlarges magnet holes parametrically. It could even be used to generate a set of test pieces with different clearances.

gluap, 2021-05-20:
An alternative solution that just sprang into my mind would be to enlarge the clearance but leave a very narrow notch to wedge the magnet against, which could hold it but would require less force to insert it. Crude ascii-art for illustration of a square magnet hole below:

```
+---v---+
|       |
>       <
|       |
+---^---+

gluap, 2021-05-23:
Following up on @opatut's lead about the magnets surviving "soldering" into the plastic: according to [supermagnete.de](https://www.supermagnete.de/faq/Wie-heiss-duerfen-Magnete-werden), the cubic magnets can be heated above 80° without damaging them thanks to their favourable aspect ratio. For the flat magnets in the display cases heat may be more of an issue and partial loss of magnetization is expected.

tobst, 2021-05-24:
After testing diferent clearances and your suggeste shape I am in favor for a script with default coordinates but different ones as an option to modify it to your needs.

tobst, 2021-05-24:
Event heating them up is a difficult task becaus they will always stick to each other or your heated metal tool.

gluap, 2021-06-19:
Regarding the cubic magnets of the main case:

I have made some experiments and arrived at a geometry that allows inserting the magnets easily while still keeping them in place a little:
- I added a cubic clearance of around 0.2 around the magnets of the MainCase in all three spatial directions.
- Clearance was added such that one layer worth of filament was left with the original dimensions. That way there is a ridge around the opening that allows to push the magnet in but which holds them in place and keeps them from jumping out. If they are too lose, they can be fixed in place using 2 component acrylic (or other suitable glue).
- Inserting them was a breeze: Have a tower of cubic magnets, push two into the MainCase and two into the USB cover, and they stay there first try.

Attached: Adapted USB cover + matching STL.

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
[adapted_plug.zip](https://github.com/openbikesensor/OpenBikeSensor3dPrintableCase/files/6680777/adapted_plug.zip)

gluap, 2021-07-08:
@tobst  what do you think of the above? I have rudimentary openscad scripts to cut this kind of holes into the case, but unless you think it makes sense I'd rather not invest the time to make them "pull-request" ready.

opatut, 2022-01-16:
I guess with the new openscad branch this becomes trivial. I'm closing this ticket in favor of the more general #34.

Closed 2022-01-16.

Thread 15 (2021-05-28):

Add loops for a little string to attach the pin to the main case

opatut, 2021-05-28:
A little hole in the pin, and one in a fitting location on the main case, would allow me to attach the pin with a string to the main body and never lose one _again_ ;)

gluap, 2021-09-28:
I just noticed that the pin already has a fitting hole. The string can be wound around one of the case screws on the case side to provide the requested functionality.

opatut, 2022-01-16:
Done, at least on `openscad` branch.

Closed 2022-01-16.

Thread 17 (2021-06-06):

OBS-Display-A-005_Kabelbinder_Schiene_v0.1.0: Change Side of the Magnet-Pocket

Carolinitzny, 2021-06-06:
The Magnet-Pocket is on the upper side in build direction, where the printer has to bridge. This is prone to inaccuracy and therefore makes putting the second magnet in very hard (if the printing wasn't as clean :)  ).
Would be nice, if the magnet-pocket is on the other side where the bridging is more accessible and easier to clean up.

tobst, 2021-06-06:
This part has been bothering me since i designed it. I would be happy to redesign. Can you provide a simple sketch to clarify your suggestion?

Carolinitzny, 2021-06-06:
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
The light green part is for the handlebar, the darker green is the part where the magnets fit in

opatut, 2022-01-16:
Hi @Carolinitzny, your suggestion was applied on the `openscad` branch at least, maybe even before in the legacy files.

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

Closed 2022-01-16.

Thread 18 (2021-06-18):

More space for display

gluap, 2021-06-18:
Currently a lot of suppliers of OLED displays seem to be switching to a new OLED display type which is slightly larger than the one previously delivered. Four out of five suppliers we tried delivered the larger display type, with some giving outright wrong measurements for the displays. The displays were electronically compatible with OBS.

The new type display board is 27.5-28mm wide and 28-29mm long, with the glass being as wide as the board, making it impossible to cut the boards down to size.

I believe an increased display opening would already allow for use of both style (small and large) boards in the same display case.

I attached a 3d Model (stl in zip) of the large-type displays as measured. The active area of the oled display is marked as a slight cutout from the display glass that is not present in the actual device.

[largedisplay.zip](https://github.com/openbikesensor/OpenBikeSensor3dPrintableCase/files/6679185/largedisplay.zip)

opatut, 2022-01-16:
Is this just a clearance problem or do we need a different geometry? I don't understand the new shape, maybe you can provide pictures, @gluap ?

gluap, 2022-01-16:
The overall geometry is the same, the difference is only the display board (and glass) width and height. You can find a working case for such displays here: https://github.com/gluap/OpenBikeSensor3dPrintableCase/tree/oversize_display/DisplayCase/SlideOnDisplay/SpecialVersions .

Essentially having the display width and height parametrized (and the hole through which one looks at the display as well) would allow for this. Clearance alone won't do it properly as the scale factors in the two dimensions of the rectangle do not necessarily match.

opatut, 2022-01-17:
So these are enough?

```
DisplayCaseTop_pcb_width = 26.5;
DisplayCaseTop_pcb_height = 27.2;
DisplayCaseTop_window_width = 21.5;
DisplayCaseTop_window_height = 12.5;
```

:)

gluap, 2022-01-19:
Yes that looks sufficient!

gluap, 2022-04-10:
with parametrized display size the issue should be solved.

Closed 2022-04-10.

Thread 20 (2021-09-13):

Welche Dateien sind die richtigen?

derlucas, 2021-09-13:
Hallo Zusammen,
aus der Doku https://www.openbikesensor.org/docs/hardware/general/case/ geht nicht hervor, welche Dateien man drucken muss.

Ich habe dem Rat entsprechend das Vertical Case gewählt und stehe vor der Frage OBS-MainCase A B C D?

Eine kurze Aufstellung der Files für ein Gehäuse samt Halterung an der Sattelstütze wäre irgendwie ganz hilfreich.

Grüße
Lucas

opatut, 2021-09-14:
[Dieser PR](https://github.com/openbikesensor/openbikesensor.github.io/pull/95) wird das vermutlich lösen.

SubOptimal, 2021-09-14:
Du kannst auch das Release Archiv herunterladen. Die Dateien sind für den OpenBikeSensor v00.03.12.

https://github.com/openbikesensor/OpenBikeSensor3dPrintableCase/releases/tag/v0.1.0

opatut, 2022-01-16:
Noch besser wird das ab sofort von https://github.com/openbikesensor/openbikesensor.github.io/pull/129 abgedeckt. Ich schließe mal dieses Ticket.

Closed 2022-01-16.

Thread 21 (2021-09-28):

Add loop for safety strap on main case

gluap, 2021-09-28:
The holding bracket of several of our OBS broke while the driver was cycling on rough ground. So far in all cases the OBS and the Bike suffered no permanent damage. The broken parts were printed by different people, with different filaments (DasFilament PETG and Tinmorry PETG) and high infill percentage in the affected area. I have created a modified bracket (attached) to reduce likelihood of this happening. Furthermore I changed the printing direction such that the layers are now parallel to the direction of the stresses in the area ("printed sideways"). The broken brackets (of the vanilla variant from the repo) were already printed with 100% infill in the affected area.

Without a safety strap on the case, a broken bracket may always result in the OBS falling into the back wheel causing the driver to fall, resulting in injury and a potentially damaged bike. To avoid this risk I imagine one could have a loop to attach a safety strap that to be secured against the seatpost.

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

[strengthened mount.zip](https://github.com/openbikesensor/OpenBikeSensor3dPrintableCase/files/7246949/strengthened.mount.zip)

A minimalist way to attach a strap could look like this, with the strap running through the grove shown in green:
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
[strap_braket.zip](https://github.com/openbikesensor/OpenBikeSensor3dPrintableCase/files/7247056/strap_braket.zip)

gluap, 2021-09-28:
[strengthened mount.zip](https://github.com/openbikesensor/OpenBikeSensor3dPrintableCase/files/7246949/strengthened.mount.zip)

gluap, 2021-09-29:
I printed a few of the thicker brakets with the simple strap clamp shown above to test them.

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

Ventusfahrer, 2021-11-25:
Hi,

I would also suggest to move the chamber more to the top.

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

Despite the current increase of the outer parts of the brackets the critical part is still unchanged (with standard slicer settings 2 outer shells and one for the inner one of the chamber). The critical part is the red marked part of the structure. Here  we have a high drag. At the right border we have pressure and in the middle nearly no force.

Moving the chamber more (or better as most as possible) to the right will move it more to the neutral line and create a higher wall thickness of the most stressed part.

On the other hand: I strongly support the exchange the standard OBS mount part with the one proposed in this change (may be with my additional proposal)

Closed 2021-12-05.

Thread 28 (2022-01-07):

WIP: OpenSCAD rewrite

opatut, 2022-01-07:
As [announced in the forum](https://forum.openbikesensor.org/t/gehaeuse-port-nach-openscad/270/2) I've started, and @gluap already helped, to port the important case files to OpenSCAD because it's open source and enables people to contribute.

I'd like to keep this issue to manage the workload, TODOs, and communicate progress with all who want to join. Comment below if you want to port a part. I'll update this post.

## MainCase
* [x] MainCase
* [x] MainCaseLid
* [x] UsbCover (WIP @gluap #26)
* [x] GpsCover

## DisplayCase
* [x] DisplayCaseBottom (@opatut)
* [x] DisplayCaseTop (@opatut)
* [x] DisplayCableStrainRelief  (@opatut)
* [x] HandlebarRail (@opatut)

## Mounting
* [x] SeatPostMount
* [x] LockingPin
* [x] StandardMountAdapter

## Alternative Mounting
* [x] #29
* [x] RackMount
* [x] AttachmentCover

These are the mounting options I want to complete first after initial porting, so we have a complete mounting solution for almost every bike.

## Deprecated or obsolete due to parametrization
* ExtendedSeatPostMount
* MainCase/HorizontalCase_JSN-AJ
* MainCase/SnapInCase_deprecated
* MainCase/TopTubeCase_deprecated_Drahtigel
* MainCase/VerticalCase_JSN-AJ/OBS-Mounting-C-002_ExtendedSeatPostMount
* DisplayCase/DisplayCase32mm
* DisplayCase/PermanentlyMounted
* DisplayCase/SlideOnDisplayV2
* DisplayCase/SnapInDisplay
* Various/

Closed 2022-01-12.

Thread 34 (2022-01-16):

Add, document and test clearance options

opatut, 2022-01-16:
The following things should be modifyable, depending on one's printer and the available hardware (magnets, screws, nuts, ...):

* Display size (#18)
* Magnet holes for USB cover (#14)
* Magnet holes in display case and handlebar rail
* M3 nuts in MainCase
* Heatset inserts in MainCase and DisplayCaseBottom

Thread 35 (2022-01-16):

OpenSCAD: Reintroduce LED holes

opatut, 2022-01-16:
There used to be a version where one could see the LEDs of the charger. We should add an option to generate these holes into the main case. I would still turn this option off by default, as the holes require extra steps during assembly.

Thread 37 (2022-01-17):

Create AttachmentCover variant with an outlet for the display cable

opatut, 2022-01-17:
One might have only one attachment port with a cable hole, but use the other one for the StandardMountAdapter, so we should have an AttachmentCover variant that has a channel for the display cable, just like the StandardMountAdapter does. We can also provide a parameter variable to disable the cable channel on the StandardMountAdapter.

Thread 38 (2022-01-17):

OpenSCAD: parameter "UsbPort_clearance" is not used

KlausMu, 2022-01-17:
I guess this parameter should be used in "MainCase.scad", but there you find hardcoded "UsbCoverMainBody(clearance=0.15)". Currently it is not used anywhere.

opatut, 2022-01-17:
Thanks for the hint. I noticed this myself while refactoring all variable names, so it's gone.

Good catch on the hardcoded value, I've now named it `MainCase_usb_port_cover_clearance` and set it to `default_clearance` in the variables file, so you can override it if you need more clearance for a good fit on that part only.

Closed 2022-01-17.

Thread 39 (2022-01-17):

OpenSCAD: feature request "rail for stem"

KlausMu, 2022-01-17:
Could you please provide a rail for a stem? Should be quite similar to the rail for the handlebar, only the tube is rotated by 90 degree - and of course some other changes needed if you rotate the tube by 90 degree. Tried to do this on my own, but I gave up after an hour. Two less experience with OpenSCAD ...

opatut, 2022-01-17:
Sure, will do. Thanks for the suggestion.

gluap, 2023-01-04:
@boldt I think you had a prototype for this.

boldt, 2023-01-04:
Yes, see here:

https://github.com/openbikesensor/OpenBikeSensor3dPrintableCase/pull/71

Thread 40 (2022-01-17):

Create TPU printable seal for display glass

opatut, 2022-01-17:
The display glass on my module is raised 1.4mm above the PCB surface. The `DisplayCaseBottom_standoff_height` is 2mm. So there is a 0.6mm gap that would be perfect for a little TPU-printed seal :)

Let's design one and try that out. Sure, not everybody can print TPU, but if we can centrall print a few hundred of them, and ship them around, then probably everybody can have one ;)

gluap, 2022-01-17:
I have some TPU around and still have the modified extruder part installed to print it. It takes surprisingly little effort to print TPU on an Ender3 (albeit very slowly and with some stringing).

Only downside: The TPU is bright green.

opatut, 2022-01-18:
Hm, I tried this, and I'm not happy with it. I think my TPU (NinjaTek Cheetah, 95A Shore) is too hard for good seals :(

I'd also still have to work on the geometry. My display should have the window shifted by 1.2-1.5mm, not 2mm, to the bottom. I will need to do some more test printing. Maybe even smaller layer height might be a good idea, then print maybe 0.7mm instead of 0.6mm to get some compression.

Basically, it'll take more time for experiments ;)

opatut, 2022-01-18:
Some day I'll try to 3D print a template or mold, then cast something in 2-part silicone. That would probably make a very nice seal :)

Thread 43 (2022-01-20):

OpenSCAS: use variable "MainCase_usb_port_cover_clearance" in "UsbCover.scad", not in "MainCase.scad"

KlausMu, 2022-01-20:
Because if USB cover and hole don't fit together, currently you have to print again the MainCase. Otherwise you only had to print again the USB cover, which is obviously much faster and needs much less filament.

gluap, 2022-01-26:
This is a very practical suggestion - But just in case you found this the hard way and are considering reprinting the MainCase - As a hotfix I'd suggest trying to print the cover with a bit of scaling in the slicer again (until the clearance is moved to the cover).

The reason this is not straightforward to implement is that the clearance is generated currently by "blowing the cover up" and the clearance will have to be thoughtfully be crafted into the cover.

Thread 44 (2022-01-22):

StandardMountAdapter: Fix wall thickness / screw head depth

opatut, 2022-01-22:
See [related forum topic](https://forum.openbikesensor.org/t/wandstaerke-im-standardmountadapter-openscad/375/6) for details.

The screw head should be a bit less deep, so there is more wall behind it to hold onto, for more strength in this critical part. The old 2mm wall thickness got ported incorrectly as 1mm, so it's a bit thin.

Adjust inside wall thickness while we're at it as well, such that neither nut nor screw head pertrudes their respective recesses, but make sure a M3x8mm bolt grabs nicely onto the nut's threads.

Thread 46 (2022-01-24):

BackRackMountCenterLongitudinal printability issues

gluap, 2022-01-24:
Incidentally the new screw clamping gap drastically worsened the printability of BackRackMountLongitudinal, because it has no direction of good printability.

Printing on this side is not optimal
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

as is printing on this other side:
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

One possible solution would be to widen the clamp (but it would be ugly). I don't think there is a good way to remove support from the small gap though. Will test-print standing on the side like in the second image with supports under the fixture for the OBS.

gluap, 2023-01-04:
Both suggested printing directions work - closing the issue.

Closed 2023-01-04.

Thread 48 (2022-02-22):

New OpenSCAD designs lack bridge helpers

codingcatgirl, 2022-02-22:
I love that you converted everything to OpenSCAD and cleaned up the repo, really awesome!

However, the new versions can't be printed without supports because bridge helpers are missing in crucial places. I've attached two examples where bridging helpers would be needed. This definitely confuses me because in `variables.scad` there's an `enable_easy_print` option which sounds like it should add bridge helpers but it looks like it doesn't, at least not in these places?

I've attached two pictures showing areas with issues and two pictures of the bridge helpers in the old version of the case for reference.

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

codingcatgirl, 2022-02-22:
Was just about to submit a pull request, then noticed it's fixed in #47 :) Cool, i'll just use that branch then.

codingcatgirl, 2022-02-22:
It is also fixed for the switch, however at the GPS hole there is still a t-shaped bridge left. Not that big a deal, but probably good to fix as well :)

gluap, 2022-02-22:
@codingcatgirl So the below screenshot is the problematic bridge, right?

To avoid double work: are you looking into it? Otherwise I'd see that I do it later.

If you are in a hurry: For me that corner wasn't beautiful but didn_t look it had structural problems either.

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

codingcatgirl, 2022-02-22:
Hey! No, i'm not looking into it right now. This one could be easily fixed by SuperSlicer's bridging features. And even if it wasn't, since it's on the inside it would have bothered me less. :)

Closed 2022-02-26.

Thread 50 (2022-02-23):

Add seal for holes

gluap, 2022-02-23:
The question of using a TPU seal for waterproofing has come up multiple times already.

The OBS MainCase currently has a whole bunch of openings that are not waterproof:
- [ ] GPS Cover lid rim
- [ ] GPS Cover Screw hole
- [ ] Cable hole
- [ ] Mounting Bracket Screw Holes
- [ ] USB Cover
- [ ] Switch
- [ ] Lid

This is about coming up with a solution for waterproofing - for instance TPU seals - Individual issues can be created by individuals working on the different openings.

As currently there are no reports of Water damage being a major issue this is mostly a "nice-to-have". Some people would like to - at least at home - be able to leave their OBS on their bike even in humid weather conditions..

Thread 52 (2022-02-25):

Critical: PCB doesn't fit into currently published designs

codingcatgirl, 2022-02-25:
What it says in the title. The current files are unusable. I've already printed two (of fifteen) and luckily just noticed early that the PCB doesn't fit. I also have an old case and it fits in there. Using the DebugPCB() module in the OpenSCAD files i can even confirm that the design ist wrong.

**WTF??**

Have the OpenSCAD files not been tested?
Should i expect more problems like this?
Should i just use the legacy files for now? Should everyone?

This is instantly noticable if you try to fit the PCB into the case. I'm glad i only found out about this after two printed cases and not later – and it looks like the PCB can at least be sanded down on the side in question. Still, **this needs urgent fixing before anyone else prints broken parts!**

Some illustrations of the problem using the DebugPCB in OpenSCAD. In the current design **the PCB is intersects with the wall**:

This is how it looks right now on the main branch:
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

This is how it looks if i move the PCB 1mm out of that wall:
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

gluap, 2022-02-26:
Very rightfully WTF. This has been in the branch for quite some time, so I'll add this warning in the forum etc.. later on. Will push a fix soon. Thank you for the issue and apologies for not noticing - with hardware devices put together and we felt safe to push this. It seems that both @opatut s and my pcb were smaller (mine was an older minor revision, likely explaining the discrepancy.  But @tobst also has a 0.03.12 PCB that shows the issue and the kicad dimensions match the board model in the repo.

gluap, 2022-02-26:
@codingcatgirl One question that comes with the merge: Were your prints from the MAIN or from the scad-generator branch? If they were from MAIN the lid won't fit after the merge - I could backport the fix to the old MAIN branch though if you already have a bunch of lids that you want to use.

codingcatgirl, 2022-02-26:
I have printed stuff from the scad-generator branch and i'm always printing the lid and main case together, so there should be no issue with that part. I found the problem with the models from the scad-generator branch and then confirmed them to be present on the main branch. So… your merge right now did not fix the problem yet!

gluap, 2022-02-26:
@codingcatgirl the issue was that my push didn't go through - I fixed in the scad generator branch but overlooked my git command line telling me that my public key was rejected. After pushing with re-passworded keepass agent it should now be fixed in both branches.

codingcatgirl, 2022-02-26:
Haha, i figured it might have been something like that. Let me quickly check if it looks alright on my side as well!

codingcatgirl, 2022-02-26:
That looks much better! However… is it intentional that the USB-C port isn't centered in its cutout now
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
?

codingcatgirl, 2022-02-26:
Also, interesting idea for the future: This might overwhelm openSCAD, but if it doesn't you could try to calculate an intersection of the PCB and the case and see if it results in an empty geometry as a safety check as part of the build/make process.

gluap, 2022-02-26:
@codingcatgirl @tobst tested the change with the latest board and reported that the space near the sensor was a bit tight (though he was able to put it together) - I pushed a fix for that as well. He's test-printing the design overnight. [status is in this forum thread](https://forum.openbikesensor.org/t/achtung-gehaeusedrucker-issue-im-maincase-von-januar-bis-heute/586/11)

codingcatgirl, 2022-02-27:
cool, thanks! i'll probably continue printing cases tomorrow, waiting for some filament to be delivered right now :D

Closed 2022-02-26.

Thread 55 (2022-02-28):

Curved bridging since latest commits

codingcatgirl, 2022-02-28:
One of the bridge helpers at the switch port has a curved perimeter, which is not ideal and defeats the purpose a bit :)

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

gluap, 2022-02-28:
I take this to mean "I expected an octagonal final layer of bridge helpers", is that right?
I stopped at a square like we had in the original design (below).

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

codingcatgirl, 2022-02-28:
no, i specifically mean the curved perimeter aliend with the outside shape of the case (top right corner) :) That wasn't like that a few days ago i think.

gluap, 2022-03-01:
I added the chage to the beta branch, it should now not be curved any more. This is what it looks sliced for me in the beta version.
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

codingcatgirl, 2022-03-04:
Sounds great. I would recommend merging it soon since i get quite a bit of a mess in this section of the part without the fix.

gluap, 2022-03-04:
It is already available [here](https://github.com/openbikesensor/OpenBikeSensor3dPrintableCase/tree/beta) - I also have a printed version that goes together, but to avoid issues with non-fitting PCBs in the future I'd rather wait until the first one of these has been built successfully (with the PCB 0.03.12, which I don't have yet.).

codingcatgirl, 2022-03-04:
With my slicing settings it looks much worse with the curve. I might have to look into that. Anyway, yes i know it's on the beta branch, it's what i'm currently printing :)

gluap, 2022-04-10:
I merged the fix to main with the latest merge from beta now that there are several cases out there with the fix.

Closed 2022-04-10.

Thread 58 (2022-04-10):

Me again! The OpenSCAD SlideOnDisplay doesn't fit either :)

codingcatgirl, 2022-04-10:
Assembled the first OBS SlideOnDisplay case today.

Doesn't fit. There's not enough space for the JST connector. Or rather… looks like it was designed for the connector to fit precisely… but not if there's cables going out of it, which is kinda the point of the connector :P

You also have to clip something off the connector on nearly all sides for it to fit.

Generally not ideal. Please fix, and test the case next time ^^

I for now will replace the connector by just soldering the cables directly to the PCB for lack of other options.

codingcatgirl, 2022-04-10:
Correction: After clipping off parts of the connector it… uh… "fits".

Which means, the display isn't held in place correctly so it there's enough for a gap for the connector to fit after all… and for the display to actually… not be held in place correctly.

Ummmmmm… ^^ Yeah, like i said. Please fix :P

codingcatgirl, 2022-04-10:
Hm, looks like there are some tweaks since i printed it. Might need to look at it. Feel free to close if these are all known fixed issues

codingcatgirl, 2022-04-10:
Yep looks like it's fixed. Oh well.

Closed 2022-04-10.

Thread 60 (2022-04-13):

Error on making a MainCaseLid with logo

Zeitungsleser, 2022-04-13:
I started `make logos`, and all the MainCase files went fine, but one the first MainCaseLid file I got following error (Ubuntu):

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

I'll attach the .svg used:
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
.

Zeitungsleser, 2022-04-13:
Fixed in Pull Request #61 https://github.com/openbikesensor/OpenBikeSensor3dPrintableCase/pull/61

Closed 2022-04-13.

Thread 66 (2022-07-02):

The screw holes are not deep enough

ovnn, 2022-07-02:
in the Last release and Main branch the screw holes are not deep enough for the M3x8mm Screws in the exportet MainCase.

gluap, 2023-01-04:
The change was merged to main, therefore i'm closing the issue.

Closed 2023-01-04.

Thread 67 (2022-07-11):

Add more default clearance

opatut, 2022-07-11:
Especially these parts, when not taken enough care of while printing, will not fit well together, so let's add more clearance:

* StandardMountAdapter / any mount (these hardly ever fit)
* USBCover / MainCase (0.2mm more will probably do)
* GPSAntennaLid / MainCase (the notch in the MainCase should be a bit wider, deeper and thicker)

gluap, 2022-10-09:
- [ ] StandardMountAdapter sliced with a current cura version fits perfectly - and I assume the fit is improved for latest prusa as well as they have switched to arachne.  I'd suggest to not change this just now because being too lose is way worse than being too tight and needing a bit of filing.
- [x] USBCover was implemented by you in 487eaf1272868e120a3e776d9efa801df8db85eb :partying_face:
- [x] GPSAntennaLid/MainCase added default_clearance to AntennaLid in d9bd1c09eff34cf3a96ab3ed9d44ad6af05f88eb

gluap, 2023-01-04:
The change is now merged to main - closing the issue.

Closed 2023-01-04.

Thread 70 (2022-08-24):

Etwas mehr Platz für das Board

boldt, 2022-08-24:
Die Heat-Insert-Löcher sind so eng aneinander, dass das einbauen der Platine in das Gehäuse tlw. nur mit Gewalt funktioniert. Wir sollten hier etwas mehr Platz schaffen, damit man die Platine "easy-peasy" einsetzen kann.

gluap, 2022-10-09:
@bold das ist mir jetzt nicht ganz klar - sind die Heatset insert Löcher zu nah aneinander (=positionen der heatset insert löcher anpassen) oder ist nicht genug Platz für das Board =case soll größer, und wenn ja in welche(n) richtungen?

mxa, 2024-06-28:
Tippfehler in mention @boldt

gluap, 2024-06-28:
Ich glaube das haben schon länger gefixt.

gluap, 2024-06-28:
Ich glaube das haben wir schon länger gefixt

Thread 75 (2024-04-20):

Display case mounting variant

mfrieling, 2024-04-20:
When pressing the button often the display moves a bit leading to (1) the button press might not be recognized because you accidentally press the whole display down and (2) you can't see whether the press has been recognized because the angle of the display has changed so that you can't see it properly, especially in sun light.

Therefore it might be better if the connection to the display holder is below the button instead of the LCD display. We are aware that the best solution would require a complete layout change of the display module as the cable outlet must be repositioned, but maybe you can think of other improvements regarding this?

imaluschi, 2025-03-22:
+1

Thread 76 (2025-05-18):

Gummierte Klettbänder

dexic79, 2025-05-18:
Hallo,

könnte man Gehäusevarianten für gummierte Klettbänder erstellen? Diese lassen sich schnell entfernen und wiederverwenden, ohne Müll mit Kabelbindern zu produzieren und sind wahrscheinlich rutschfester als Kabelbinder.

Vielen Dank für das tolle Projekt!

Herzliche Grüße
dexic

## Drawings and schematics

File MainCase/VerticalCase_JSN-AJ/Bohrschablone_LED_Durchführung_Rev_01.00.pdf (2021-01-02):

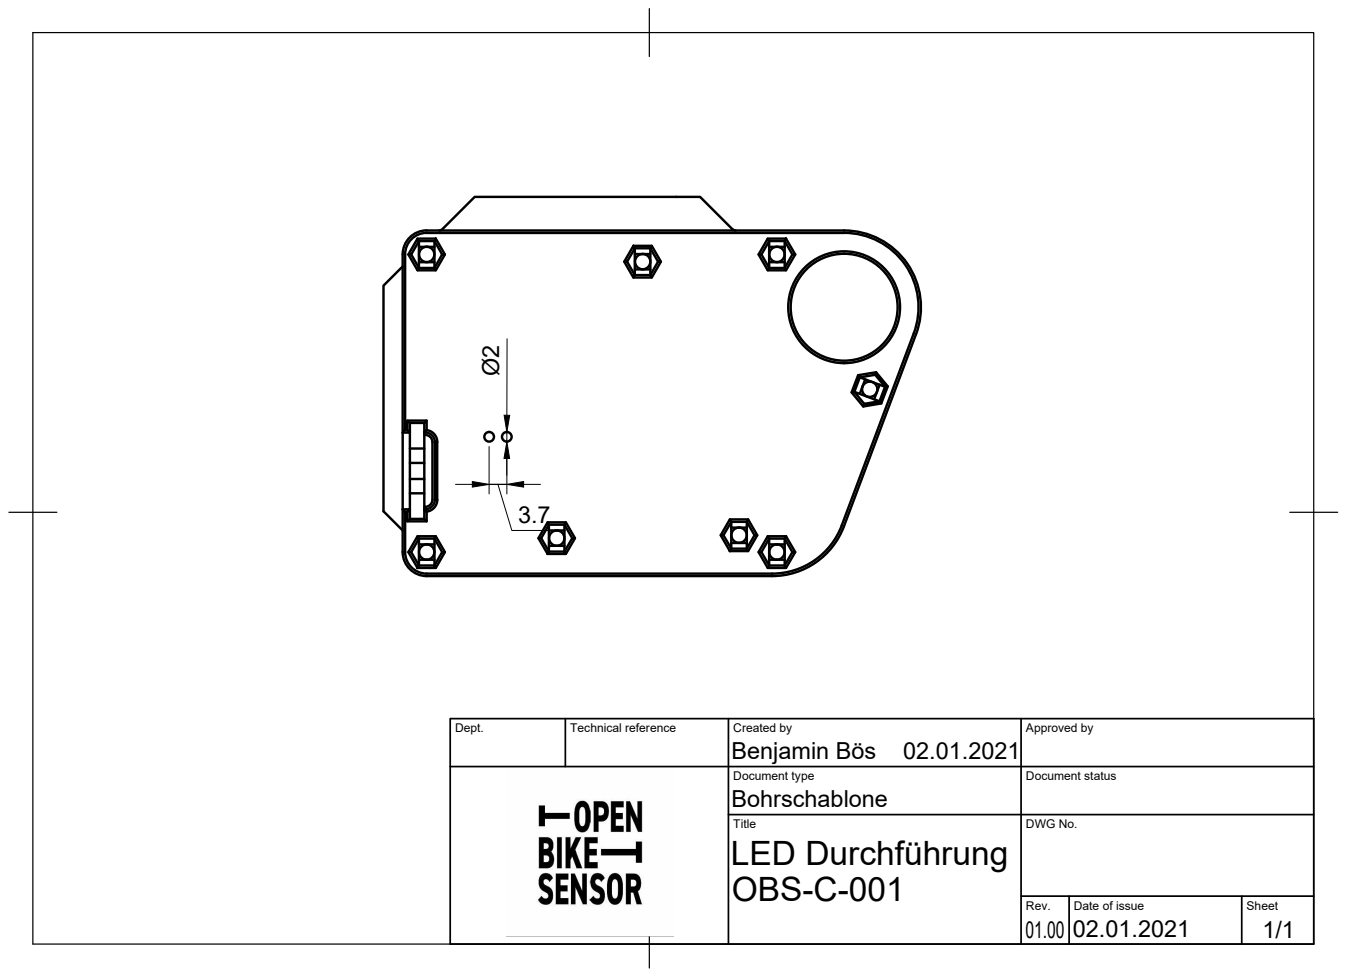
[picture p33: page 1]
Benjamin Bös Ø2

Dept. | Technical reference | Created by 02.01.2021 | Approved by

Document type Bohrschablone | Document status

Title LED Durchführung OBS-C-001 | DWG No.

Rev. 01.00 | Date of issue 02.01.2021 | Sheet 1/1

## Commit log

2020-05-23 32mm version of the display and button case
    [KnopfZusammenbau.iam, Oberschale.ipt, Oberschale.stl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]
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2020-07-16 fixed size
    [DisplayClip26_8.ipt]
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2020-10-29 clip and bracket for 22.2mm on top of brake
    [Bracket22_2.ipt, Bracket22_2.stl, DisplayClip22_2_4mmbrake.ipt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]
2020-11-21 alternative mounting system for vertical case display fitting 22mm handlebars
    [OBS-A-001-AlternativeMount22mmSlide.stl, OBS-A-002-AlternativeMount22mmTop.stl, OBS-A-003-AlternativeMount22mmBottom.stl]
2020-12-02 separate main and display cases, more consistent naming
    [OBS-C-001-V1.step, OBS-C-001-V1.stl, OBS-C-002-V1.step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]
2020-12-02 also move new files to separate display and main case folders
    [Bracket22_2.ipt, Bracket22_2.stl, Deckel_Logo.ipt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]
2020-12-29 Added 22.2mm and 25.4mm variants for the SlideOnDisplay clamp renamed the original clamp OBS-D-006 v10.stl and OBS-D-007 v10.stl to the 31_8 variants new variants with 22.2mm and 25.4mm have V11
    [OBS-D-006 v10_31_8.stl, OBS-D-006 v11_22_2.stl, OBS-D-006 v11_25_4.stl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]
2021-01-02 Added a OBS-C-001 Variant with LED Holes if no transparent filament is used
    [OBS-C-001 v44_with_LED_holes.step, OBS-C-001 v44_with_LED_holes.stl]
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2021-01-08 Added a V2 of the SlideOnDisplayV2/OBS-D-201_V1.f3z
    No more custom 3D printed clamp is needed, regular hose clamp is enought
    new magnet in 10x5x2.5mm
    only 3 parts needed from now on
    [OBS-D-201_V1.f3z, OBS-D-201_V1.step, OBS-D-201_V1.stl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]
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2021-01-09 Added Data for the cable grommet Added a V2, that is kind of waterproof
    [OBS-D-201_V2.f3z, OBS-D-201_V2.step, OBS-D-201_V2.stl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]
2021-01-18 OBS-D-003 v13_Schlauchschelle_hybride.stl only needs a tube/hose clamp from a hardware store is a little hybrid because it has already the new magnet hole in the bottom for the SlideOnDisplayV2 but h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
    [OBS-D-003 v13_Schlauchschelle_hybride.stl]
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2021-02-11 Extend height of print by 0.1mm - This change results in people not having to change layer-heights while printing to get two layers before the filament change
    [OBS-C-002 v31.step, OBS-C-002 v31.stl, OBS-C-002 v32.step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]
2021-02-15 Fix: re-introduce screw-holes
    [OBS-C-002 v32.step, OBS-C-002 v32.stl]
2021-02-19 fixed the to small Display Coutout in OBS-D-201_V2.stl
    [OBS-D-201_V2.f3z, OBS-D-201_V2.step, OBS-D-201_V2.stl]
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2021-02-21 added missing lower part for SlideOnDisplayV2 SlideOnDisplayV2/OBS-D-202_V4.step
    [OBS-D-202_V4.step, OBS-D-202_V4.stl]
2021-02-21 removed older and false Versions of OBS-D-202 (V1 V2)
    [OBS-D-202_V1.step, OBS-D-202_V1.stl, OBS-D-202_V2.step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]
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2021-03-09 added missing files for usb and pin
    [OBS-C-003_v15.stl, OBS-M-003_v4.stl]
2021-03-11 move display away from tube it is mounted on
    [90deg_bottom_v2.ipt, 90deg_bottom_v2.stl, 90deg_top_v2.ipt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]
2021-03-11 updated OBS-D-003 v13_Schlauchschelle_hybride to OBS-D-003 v14_Schlauchschelle_hybride and added step and f3d for this
    [OBS-D-003 v13_Schlauchschelle_hybride.stl, OBS-D-003 v14_Schlauchschelle_hybride.f3d, OBS-D-003 v14_Schlauchschelle_hybride.step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]
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2021-04-17 Fix logo-case-generator README
2021-04-21 default inverted=false
    [logo-lid.scad]
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2021-04-21 fixe height
    [OBS-VerticalCase-M-002-Oberrohr.ipt, OBS-VerticalCase-M-002-Oberrohr.stl, OBS-VerticalCase-M-002-Oberrohr.stp]
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2021-04-24 Fix lid stl reference
    The lid stl file name has changed, this adapts the scad file to fix the logo generator.
    [logo-lid.scad]
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2021-04-29 introduce naming and versioning scheme for display, add heat set insert display case
    [OBS-A-001-AlternativeMount22mmSlide.stl, OBS-A-002-AlternativeMount22mmTop.stl, OBS-A-003-AlternativeMount22mmBottom.stl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]
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2021-06-07 reset magnet holes to original size
    [OBS-MainCase-A-001_MainCase_without_logo_v0.1.4.ipt, OBS-MainCase-A-001_MainCase_without_logo_v0.1.4.stl, OBS-MainCase-A-001_MainCase_without_logo_v0.1.4.stp]
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2021-12-05 Add strengthened mount to avoid clamps breaking.
    [OBS-Mounting-A-001_StandardOBSMount_v0.1.2.f3d, OBS-Mounting-A-001_StandardOBSMount_v0.1.2.stl, OBS-Mounting-A-001_StandardOBSMount_v0.1.2.stp]
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2022-01-03 Flip MainCaseLid correctly
    [MainCaseLid.scad]
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2022-01-05 We need a bit more space for the sensor boards. Also USB port needs more wall thickness to be printable
    [MainCase.scad]
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2022-01-07 Missed one line
    [UsbCover.scad]
2022-01-07 remove duplicate code, fix missing line
    [MainCase.scad, UsbCover.scad]
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2022-01-07 fixed wall width
    [MainCase.scad]
2022-01-07 Make heatset insert holes bigger at bottom to fill with pushed down plastic
    [MainCase.scad, variables.scad]
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2022-01-09 Move MountRail to utils, add clearance parameter
    [DisplayCaseTop.scad, HandlebarRail.scad, MainCase.scad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]
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2022-01-10 Make preview faster, add `fast` parameter, and rotate some parts for previews
    [DisplayCableStrainRelief.scad, HandlebarRail.scad, MainCaseLid.scad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]
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2022-01-11 Fix main case lid rim
    [MainCase.scad, MainCaseLid.scad, variables.scad]
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2022-01-11 Fix variable names and add width/height for micro usb hole
    [MainCase.scad, variables.scad]
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2022-01-12 adapt to strengthened version from master
    [StandardMountAdapter.scad, variables.scad]
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2022-01-14 DisplayCase: Fix magnet hole depths
    [DisplayCaseBottom.stl, DisplayCaseTop.stl, variables.scad]
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2022-01-14 Calibration: reduce size of calibration prints to cover only a reasonable range
    [HexNuts.stl, ScrewHoles.stl]
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2022-01-15 add a radius to the corner that will likely receive the most stress.
    [BackRiderTopRiderAdapter.scad, BackRiderTopRiderAdapter.stl, MainCase.scad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]
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2022-01-17 Add clearance parameter for USB port in MainCase, see #38
    [MainCase-inverted-highlight.stl, MainCase.scad, variables.scad]
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2022-01-29 printability fixes that help brdiging (and which were present in the original case)
    [MainCase.scad, UsbCover.scad]
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2022-01-31 fix trigonometry for "frontside angle"
    [MainCase.scad, MainCaseLid.scad, variables.scad]
2022-01-31 small gemotry alterations to fix manifold issues
    [MainCase.scad]
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2022-01-31 another small geometry fix.
    [MainCase.scad]
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2022-02-01 0.5mm thicknes for the antenna tab keeper is brittle just one line at .4 nozzle. increase lid thickness accordingly and make it scale intelligently.
    [variables.scad]
2022-02-01 re-render of all case parts, there were quite a few changes, so I'm not entirely sure what parts have NOT been touched - submit everything that may be affected
    [AttachmentCover.stl, BackRiderTopRiderAdapter.stl, BikeRackMountCenter.stl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]
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2022-02-02 faster logo build by cutting logo out of stl instead of re-rendering full case every build.
    [MainCase.scad, MainCaseLid.scad, variables.scad]
2022-02-15 fix the rim such that the sensor corner has less flex.
    [MainCase.scad, MainCaseLid.scad]
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2022-02-22 - Add printability chamfer to micro usb plug opening - AttachmentCover should not have a number in the plain variant
    [AttachmentCover.scad, AttachmentCover.stl, MainCase.scad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]
2022-02-22 rebuild everything with sorted vertices (and fix Makefile tabs...)
    [AttachmentCover.stl, BackRiderTopRiderAdapter.stl, BikeRackMountCenter.stl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]
2022-02-26 move pcb up by 1.5mm to fix issue with pcb overlapping into shape
    [MainCase-inverted-highlight.stl, MainCase.scad, variables.scad]
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2022-02-26 @tobst found one more issue: sensor was touching the board. Was assemblable but touching ain't good. this moves the sensor back by 2mm (now having fixed the slope parametrization pays off).
    [MainCase-inverted-highlight.stl, MainCase.scad, MainCaseLid-inverted-highlight.stl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]
2022-02-27 Move usb port in sync with screw holes.
    This is a geometric noop - as evidenced by the the MainCase.stl not changing, but it ensures that the
    USB hole stays in the correct location when the wall thickness is changed.
    [variables.scad]
2022-02-28 fix slight printability helper issue in switch cavity.
    [MainCase-inverted-highlight.stl, MainCase.scad, MainCaseLid.scad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]
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2022-03-04 geometry fixes: - Built STL for Lid and MainCase wall with thinner wall around the sensors (so the silicone grippers don't get stuck and Sensors insert more easily) - More space for cables in Display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
    [AttachmentCover.stl, BackRiderTopRiderAdapter.stl, BikeRackMountCenter.stl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]
2022-03-12 No geometry changed - add "stl fixing" and selection from parts list to customizer.
    [MainCase.scad, MainCaseLid.scad, variables.scad]
2022-03-15 fix issues: - Display Case was very narrow for plug - Magnet holes were tiny for magnets.
    [DisplayCaseBottom.scad, DisplayCaseBottom.stl, DisplayCaseTop.scad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]
2022-03-15 fix issues: - strain relief should allow using M3 screw
    [DisplayCableStrainRelief.scad, DisplayCableStrainRelief.stl]
2022-04-07 fix issues: - MAIN Case was a bit tight for the 0.03.12 board - extended by 2mm to make it easier on first-time builders.
    [MainCase.scad, variables.scad]
2022-04-18 Fix issues that lead to openscad crashing in "use prebuild" mode.
    [MainCase.scad, MainCaseLid.scad]
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2022-04-20 small changes to avoid geometry problems preventing make from cached lid.
    [MainCaseLid.scad]
2022-04-24 make GPS antenna housing top width and housing holde width customizable no geometrical change in default version
    [variables.scad]
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2022-05-08 HandlebarRail bridging issues and magnet holes smaller than some magnets.
    [variables.scad]
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2022-05-09 missing clearance for switch hole
    [MainCase.scad]
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2022-05-09 A bit more tolerance on the usb hole (to avoid people from having to work picture-perfect with the heatset inserts.
    [MainCase.scad]
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2022-05-11 fix seatpost mount cable binder openings
    [SeatPostMount.scad]
2022-05-12 Fixed seatpostmount (#64)
    * fix seatpost mount cable binder openings
    * up version
    [SeatPostMount.scad, SeatPostMount.stl, TopTubeMount.stl]
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2022-06-02 add parameter for MountRail Clearance
2022-07-26 Add corrective clearance for UsbCover (#68)
    * Add corrective clearance for UsbCover
    * actually default to correcting clearance in UsbCover
    [UsbCover.scad, UsbCover.stl, variables.scad]
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2022-10-09 Use the default clearance also for the antenna lid. Attempt at #67
    [MainCase.scad]
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2022-10-27 in test prints this was not bridging-friendly. Leave a bit of a ledge for the bridge.
    [DisplayCaseBottom.scad]
2023-01-03 Change DisplayCaseTop to: - accomodate nut even for shorter buttons - add space to finally allow to use the connector on the display without cutting it to size.
    [DisplayCaseTop.scad, variables.scad]
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2023-01-06 Add the stls for 0.3.38 so people also find the current files in export.
    [BikeRackMountCenter.stl, BikeRackMountCenterLongitudinal.stl, BikeRackMountSide.stl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]
2023-03-25 OBS Lite: - working screwmounts - attaches to StandardMountAdapter - including pcb spacer
    [LiteCase.scad, LiteCase_bottom.scad, Sensor_spacer.scad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]
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2024-03-23 extend top cap and adapt keystem clearance.
    [buttonmount_cherry.scad, variables.scad]
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2026-07-07 fix angle caĺculations for large radiuses of the seatpost
    [SeatPostMount.scad]
